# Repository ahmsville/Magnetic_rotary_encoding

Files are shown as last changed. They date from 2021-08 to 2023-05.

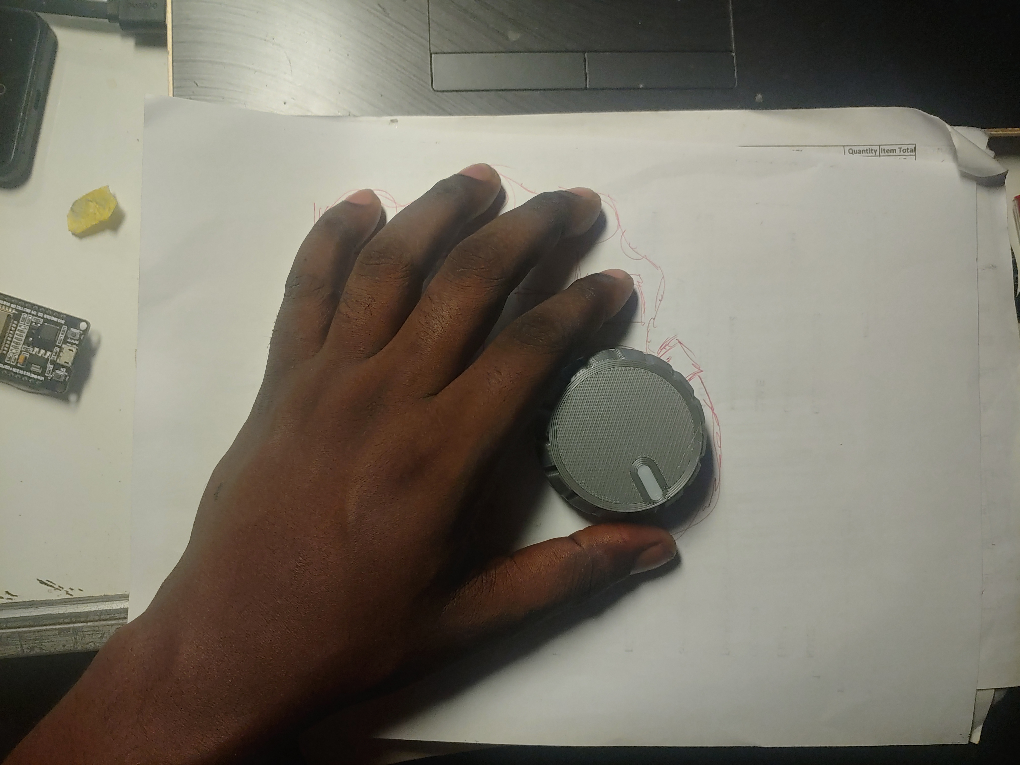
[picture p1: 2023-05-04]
PICO DEV M3/PICO DEV M3 KEYPAD/20230124_191834_HDR.jpg

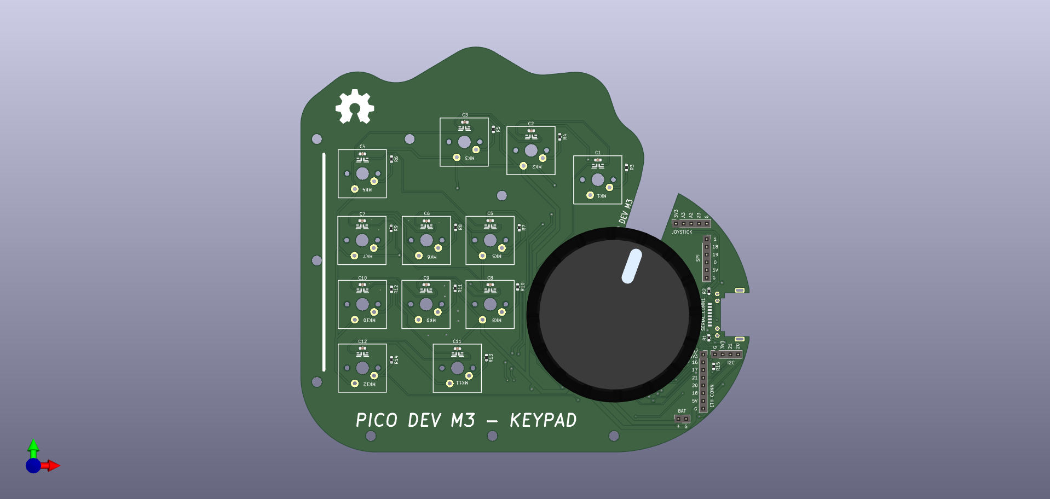
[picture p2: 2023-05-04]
PICO DEV M3/PICO DEV M3 KEYPAD/PICO DEV M3 KEYPAD.png

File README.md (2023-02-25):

# Magnetic_Rotary_Encoding

## Learn more about this project - 
 - https://www.ahmsvillelabs.io/projects/magnetic-rotary-encoding
 - https://youtu.be/atb6d4b-VYk
 - https://youtu.be/_1tGosBLRB0

## BUILD INSTRUCTIONS
 - https://www.ahmsvillelabs.io/magnetic-rotary-encoderbuild

# Hardware Options



 ## 1. Magnetic Rotary Encoder 
 This is standalone encoder made to connect to a seperate microcontroller like an Arduino board, this version has a base resolution of 72, extendable up to 72000 steps per revolution.
 magnetic rotary encoder pinout

 ### Features:
- Capacitive touch / button input
- Addressable Led ring (18 LEDs)
 ### Supported Boards / Platform:
- **All Arduino Boards** 
- **Raspberry Pi Pico C/C++ SDK** 
- **All Micropython-Supported Boards**

## 2. Magnetic Rotary Encoder MINI 
 This is standalone encoder similar to the first option, only with a small form factor, this version has a base resolution of 36, extendable up to 36000 steps per revolution.
 magnetic rotary encoder mini pinout

  ### Features:
- Capacitive touch / button input
- Addressable Led ring (12 LEDs)
 ### Supported Boards / Platform:
- **All Arduino Boards** 
- **Raspberry Pi Pico C/C++ SDK** 
- **All Micropython-Supported Boards**

## [3. Pico Dev M3](https://github.com/ahmsville/Magnetic_rotary_encoding/tree/master/PICO%20DEV%20M3) 
 This is a full fledged development board combined with the magnetic rotary encoder, its built with the Raspberry Pi RP2040 microcontroller chip with a base resolution of 36, extendable up to 36000 steps per revolution.
 pico dev m3 pinout

  ### Features:
- RP2040 chip, Dual-core Arm Cortex-M0+ processor at 133 MHz
- 264kB on-chip SRAM
- 128Mb on-board QSPI flash
- 19 multifunction GPIO pins, with 2 analog inputs
- 2 UARTs
- 2 SPI controllers
- 2 I2C controllers
- 16 PWM channels
- USB 1.1 controller with host and device support
- 8 PIO state machines
- USB type C
- Lipo charging
- onboard Button input
- Addressable Led ring (18 LEDs)
 ### Supported Platform:
- **RP2040 C/C++ SDK** 
- **Micropython**

# How to connect and use the [Ahmsville labs magnetic rotary encoder](https://www.tindie.com/products/22156/).

There are three ways to connect the magnetic rotary encoder, all with their benefits and draw backs.

## 1. Analog only Detection: 

in this mode the library uses just the signals from the hall effect sensors to make sense of the rotation of the encoder. the benefit of this mode is that you only need two analog pins to do all the rotation encoding, also been analog means you can use the libraries built in interpolation mode for an extremely high and granular resolution. The drawback is, this mode requires constant polling of the sensors which is not ideal for a complex system, also if the board does not have analog pins or if your setup cannot spare any of them, then you cannot use this mode.

## Connection

To use this mode, simply connect ENC-1 and ENC-2 to two analog input pins, you may also connect the LED pin to any available pin on the board. VCC  should be connected to the same voltage level used by the microcontroller on the boards, so power the encoder with 5v if the board uses 5v, and power it with 3.3v it the board uses 3.3v, you should offcus also connect the GND pin.

Asset 1

## Code

To test the example code, all you have to do is activate the analog only mode and change the pin assignment according to your connections. For the mode, you have the option to choose continuous rotation detection which returns a continuous count in either direction, or absolute positioning, which returns a value within the encoder’s base resolution, you can also choose the extended interpolated resolution mode for a super-duper high resolution.

## C/C++

```c++
#define ENCMODE 1 // BASE RESOLUTION ANALOG ONLY
//#define ENCMODE 2 // BASE RESOLUTION ANALOG ONLY ABSOLUTE POSITIONING
//#define ENCMODE 3 // EXTENDED RESOLUTION ANALOG ONLY
//#define ENCMODE 4 // BASE RESOLUTION ANALOG AND DIGITAL
//#define ENCMODE 5 // BASE RESOLUTION ANALOG AND DIGITAL ABSOLUTE POSITIONING
//#define ENCMODE 6 // EXTENDED RESOLUTION ANALOG AND DIGITAL
//#define ENCMODE 7 // BASE RESOLUTION DIGITAL ONLY
//#define ENCMODE 8 // BASE RESOLUTION DIGITAL ONLY ABSOLUTE POSITIONING
```

```c++
#define E1_ADC_PIN 26 // ADC PIN for hall sensor 1
#define E2_ADC_PIN 27 // ADC PIN for hall sensor 2
```

## MicroPython

```python
ENCMODE = 1 # BASE RESOLUTION ANALOG ONLY
#ENCMODE  = 2 # BASE RESOLUTION ANALOG ONLY ABSOLUTE POSITIONING
#ENCMODE  = 3 # EXTENDED RESOLUTION ANALOG ONLY
#ENCMODE  = 4 # BASE RESOLUTION ANALOG AND DIGITAL
#ENCMODE  = 5 # BASE RESOLUTION ANALOG AND DIGITAL ABSOLUTE POSITIONING
#ENCMODE  = 6 # EXTENDED RESOLUTION ANALOG AND DIGITAL
#ENCMODE  = 7 # BASE RESOLUTION DIGITAL ONLY
#ENCMODE  = 8 # BASE RESOLUTION DIGITAL ONLY ABSOLUTE POSITIONING
```

```python
E1_ADC_PIN = 26  # ADC PIN for hall sensor 1
E2_ADC_PIN = 27  # ADC PIN for hall sensor 2
```

## 2. Analog and Digital Detection: 

in this mode the library uses the signals from the hall effect sensors together with two additional digital interrupt enabled input pins. This mode has all the same features and benefits as the analog only detection mode without the need for constant polling of the hall effect sensors, this is extremely usefull for complex systems, as the interrupt pins notify the code of when a rotation occurs, so constant polling is not needed, this mode is in fact the mode used on the [Ahmsville Dial V2](https://youtu.be/yGbshYLfDnc).
Please note that the code will return to constant polling if you select the Extended Resolution mode, since this process requires interpolation between the encoder’s steps.

## Connection

To use this mode, simply connect ENC-1 and ENC-2 to two analog input pins, and E1-INT1 and E2-INT1 to two interrupt enabled pins on the board, you may also connect the LED pin to any available pins on the board. VCC  should be connected to the same voltage level used by the microcontroller on the boards, so power the encoder with 5v if the board uses 5v, and power it with 3.3v it the board uses 3.3v, you should offcus also connect the GND pin.

Asset 2

Depending on your encoder version, you may also need to bridge the config pads on the PCB to use this mode.
ASDADASDASDASDAS

## Code

To test the code, all you have to do is activate the analog and digital mode and also change the pin assignment according to your connections. For this mode, you also have the option to choose continuous rotation detection which returns a continuous count in either direction, or absolute positioning, which returns a value within the encoder’s base resolution, you can also choose the extended interpolated resolution mode for a super-duper high resolution.

## C/C++

```c++
//#define ENCMODE 1 // BASE RESOLUTION ANALOG ONLY
//#define ENCMODE 2 // BASE RESOLUTION ANALOG ONLY ABSOLUTE POSITIONING
//#define ENCMODE 3 // EXTENDED RESOLUTION ANALOG ONLY
#define ENCMODE 4 // BASE RESOLUTION ANALOG AND DIGITAL
//#define ENCMODE 5 // BASE RESOLUTION ANALOG AND DIGITAL ABSOLUTE POSITIONING
//#define ENCMODE 6 // EXTENDED RESOLUTION ANALOG AND DIGITAL
//#define ENCMODE 7 // BASE RESOLUTION DIGITAL ONLY
//#define ENCMODE 8 // BASE RESOLUTION DIGITAL ONLY ABSOLUTE POSITIONING
```

```c++
#define E1_INT1 16 // hall sensor 1 interrupt pin 1
#define E2_INT1 18 // hall sensor 2 interrupt pin 1

#define E1_ADC_PIN 26 // ADC PIN for hall sensor 1
#define E2_ADC_PIN 27 // ADC PIN for hall sensor 2
```

## MicroPython

```python
#ENCMODE = 1 # BASE RESOLUTION ANALOG ONLY
#ENCMODE  = 2 # BASE RESOLUTION ANALOG ONLY ABSOLUTE POSITIONING
#ENCMODE  = 3 # EXTENDED RESOLUTION ANALOG ONLY
ENCMODE  = 4 # BASE RESOLUTION ANALOG AND DIGITAL
#ENCMODE  = 5 # BASE RESOLUTION ANALOG AND DIGITAL ABSOLUTE POSITIONING
#ENCMODE  = 6 # EXTENDED RESOLUTION ANALOG AND DIGITAL
#ENCMODE  = 7 # BASE RESOLUTION DIGITAL ONLY
#ENCMODE  = 8 # BASE RESOLUTION DIGITAL ONLY ABSOLUTE POSITIONING
```

```python
E1_INT1 = 16 # hall sensor 1 interrupt pin 1
E2_INT1 = 18 # hall sensor 2 interrupt pin 1

E1_ADC_PIN = 26 # ADC PIN for hall sensor 1
E2_ADC_PIN = 27 # ADC PIN for hall sensor 2
```

## 3. Digital only Detection: 

in this mode the library uses only digital interrupt enabled input pins; four of them. This mode is similar in operation to traditional rotary switches, the analog signals from the hall effect sensors have been converted to digital signals using comparators, so no analog input pins are required. This mode was developed for systems that don’t have or cannot spare analog input pins, its also the fastest mode and requires zero polling, which is why I used it to encode the [Pick N Place Wheel](https://youtu.be/MtNO8-5vCqg). 
Because this mode uses digital signals alone, you cannot use the interpolated extended resolution mode that is available in the previous modes.

## Connection

To use this mode, simply connect E1-INT1, E1-INT2, E2-INT1 and E2-INT2 to four interrupt enabled pins on the board, you may also connect the LED pin to any available pins on the board. VCC  should be connected to the same voltage level used by the microcontroller on the boards, so power the encoder with 5v if the board uses 5v, and power it with 3.3v it the board uses 3.3v,  also connect the GND pin.

Asset 3

## Code

To test the code, all you have to do is activate the digital only mode and also change the pin assignments according to your connections. For this mode, you have the option to choose continuous rotation detection which returns a continuous count in either direction, or absolute positioning, which returns a value within the encoder’s base resolution.

## C/C++

```c++
//#define ENCMODE 1 // BASE RESOLUTION ANALOG ONLY
//#define ENCMODE 2 // BASE RESOLUTION ANALOG ONLY ABSOLUTE POSITIONING
//#define ENCMODE 3 // EXTENDED RESOLUTION ANALOG ONLY
//#define ENCMODE 4 // BASE RESOLUTION ANALOG AND DIGITAL
//#define ENCMODE 5 // BASE RESOLUTION ANALOG AND DIGITAL ABSOLUTE POSITIONING
//#define ENCMODE 6 // EXTENDED RESOLUTION ANALOG AND DIGITAL
#define ENCMODE 7 // BASE RESOLUTION DIGITAL ONLY
//#define ENCMODE 8 // BASE RESOLUTION DIGITAL ONLY ABSOLUTE POSITIONING
```

```c++
#define E1_INT1 16 // hall sensor 1 interrupt pin 1
#define E1_INT2 17 // hall sensor 1 interrupt pin 2
#define E2_INT1 18 // hall sensor 2 interrupt pin 1
#define E2_INT2 19 // hall sensor 2 interrupt pin 2
```

## MicroPython

```python
#ENCMODE = 1 # BASE RESOLUTION ANALOG ONLY
#ENCMODE  = 2 # BASE RESOLUTION ANALOG ONLY ABSOLUTE POSITIONING
#ENCMODE  = 3 # EXTENDED RESOLUTION ANALOG ONLY
ENCMODE  = 4 # BASE RESOLUTION ANALOG AND DIGITAL
#ENCMODE  = 5 # BASE RESOLUTION ANALOG AND DIGITAL ABSOLUTE POSITIONING
#ENCMODE  = 6 # EXTENDED RESOLUTION ANALOG AND DIGITAL
#ENCMODE  = 7 # BASE RESOLUTION DIGITAL ONLY
#ENCMODE  = 8 # BASE RESOLUTION DIGITAL ONLY ABSOLUTE POSITIONING
```

```python
E1_INT1 = 16  # hall sensor 1 interrupt pin 1
E1_INT2 = 17  # hall sensor 1 interrupt pin 2
E2_INT1 = 18  # hall sensor 2 interrupt pin 1
E2_INT2 = 19  # hall sensor 2 interrupt pin 2
```

# Complimentary Input on the Encoder

You have two options when it comes to complimentary input on the encoder, you can choose to use capacitive touch or a normal push button, both the capacitive touch and the push button will be included with the kit if you buy it from [my store](https://www.tindie.com/products/22156/).
To use capacitive touch, you will need an Arduino board, if you use other development boards like the ESP32 or Raspberry PI Pico, you will have to use the push button.

SAGSAFFF
zczczczcc

## Capacitive touch
To use the capacitive touch on an Arduino, you must have assembled the encoder according to the instructions, so that you can simply connect CT1 and CT2 to two available pins and then update the pin assignment in the example code accordingly.

## C/C++

```c++
#define CT1 5 // CAPACITIVE TOUCH (CT1)
#define CT2 6 // CAPACITIVE TOUCH (CT2)
```

## Push button
To use the push button, you should solder the included button to the encoder board and then connect only CT1 to an available pin on the development board.

## C/C++

```c++
#define CT1 15 // PUSH BUTTON (CT1)
```

## MicroPython

```python
CT1 = 15 # PUSH BUTTON (CT1)
```

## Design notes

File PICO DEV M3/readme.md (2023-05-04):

# PICO DEV M3



The **Pico Dev M3** is a development board based on Raspberry Pi's **RP2040 microcontrolle**r chip, the board is also a high-resolution **magnetic rotary encoder** when paired with a few 3D printed parts, which makes this the perfect board for applications and projects that can benefit from having a rotary encoder, a good example is making macro pads, and other similar secondary controllers.

## **Board Features**
- RP2040 chip, Dual-core Arm Cortex-M0+ processor at 133 MHz
- 264kB on-chip SRAM
- 128Mb on-board QSPI flash
- 19 multifunction GPIO pins, with 2 analog inputs
- 2 UARTs
- 2 SPI controllers
- 2 I2C controllers
- 16 PWM channels
- USB 1.1 controller with host and device support
- 8 PIO state machines
- USB type C
- Lipo charging
- onboard Button input
- Addressable Led ring (18 LEDs)

## **Encoder Features**

- The onboard encoder features a base resolution of **36 steps, extending up to 36000** steps per revolution.
- There’s also a ring of **18 individually addressable LEDs** on board.
- Features a ball bearing which gives the encoder a significantly smoother feel compared to traditional rotary encoders.
- Customizable 3d printed encoder. 
- Implementing the encoder is also really straightforward using the dedicated Libraries and Sample Codes
- Easy mounting options

### **Programming Language:**

- **RP2040 C/C++ SDK** 
- **Micropython**

pico dev m3 pinout

## **Sample Projects Based on the PICO DEV M3:**

ZVE00216 (3)

- **Pico Dev M3 Keypad** 

ZVE00234 (2)

This is a 12-key macropod that uses the Pico dev m3 as its controller, the breakout board features backlit keys, headers for connecting I2C, SPI, and UART peripherals, and a header for connecting a joystick module to the Pico dev m3, you can power the keypad from the type c port on the pico dev m3 board or with a Lipo battery connected to the BAT header, taking advantage of the Lipo charge controller built into the pico dev m3.
- **PIO Stepper Controller**

ZVE00231 (2)

This breakout board allows you to use this Programmable IO (PIO) on the RP2040 chip on the Pico dev m3 to individually control 3 stepper motors. This board can be used to control any 3-axis motion system, robot, or custom mechanism.

## BUILD INSTRUCTIONS
 - https://www.ahmsvillelabs.io/magnetic-rotary-encoderbuild/pico-dev-m3

### **Encoder Assembly:**

- Sandwich the pico dev m3 board between the **BOARD BUTTON** and **BOARD TOP** 3D printed parts, and secure them together using 3 **M1.4x6mm** self-tapping screws.

Capture

CaptureXCXC

- Attach **608 bearing (8x22x7)** to the assembly and secure it with the **BEARING HOLDER** part and 1 **M2x8mm** self-tapping screw.

CapturZDCe

- Install **(18pcs) 3x1mm** neodymium magnets to the KNOB in an alternating pole configuration.
Depending on your 3D printer's tolerance you may use super glue to secure the magnets, but if the holes turn out as the perfect size, a simple press-fit is sufficient.

CaptuGGre

- Attach the knob to the bearing.

CaptFHNFure

- For Flexibility, you may print the **BUTTON BASE** file this allows the pico dev m3 encoder and button to be used conviniently, the button base attaches to the pico dev encoder via 2 **M2x8mm** selftapping screws.

Capgfgture

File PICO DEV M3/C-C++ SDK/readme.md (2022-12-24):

# Pico Dev M3 C/C++ SDK

The board will come with a default firmware loaded, so you should be able to just connect it to a computer and see the output from a serial terminal like putty or arduino's serial monitor. The default firmware is in C/C++ and you can download the UF2 file [**here.**](https://github.com/ahmsville/Magnetic_rotary_encoding/tree/master/PICO%20DEV%20M3/C-C%2B%2B%20SDK/PICO%20DEV%20M3/build) 

To use the C/C++ code for the pico dev m3, you should alredy have your computer setup to program a Raspberry pi pico using the C/C++ SDK, if not, i recommend watching this [video from Learn Embedded Systems](https://www.youtube.com/watch?v=mUF9xjDtFfY) or you can follow the official instructions at [**Raspberry Pi Documentation.**](https://www.raspberrypi.com/documentation/microcontrollers/c_sdk.html)

This page contains the project folder for the pico dev m3, you can download it and build it yourself, i personally use visual studio code to build my RP2040 projects, and its just a matter of adding the folder to the workspace and allowing the project to configure itself, you can then click on build.
Captuzvdfdsfsdfre

To load the compiled firmware to the pico dev m3, simply copy the generated UF2 file located in the build folder to the board by connecting to the board via the usb type c port while holding the BOOTSEL button at the back of the board, reference the pinout diagram.

## Changing the encoding method used on the board.

Please see the main [Magnetic rotary encoder](https://github.com/ahmsville/Magnetic_rotary_encoding) page for details on the differences between the modes listed below.

To switch modes, simply uncomment one of this lines in the example code

```C++
// #define ENCMODE 1 // BASE RESOLUTION ANALOG ONLY
#define ENCMODE 2 // BASE RESOLUTION ANALOG ONLY ABSOLUTE POSITIONING
// #define ENCMODE 3 // EXTENDED RESOLUTION ANALOG ONLY
// #define ENCMODE 4 // EXTENDED RESOLUTION ANALOG ONLY ABSOLUTE POSITIONING
// #define ENCMODE 5 // BASE RESOLUTION ANALOG AND DIGITAL
// #define ENCMODE 6 // BASE RESOLUTION ANALOG AND DIGITAL ABSOLUTE POSITIONING
// #define ENCMODE 7 // EXTENDED RESOLUTION ANALOG AND DIGITAL
// #define ENCMODE 8 // EXTENDED RESOLUTION ANALOG AND DIGITAL ABSOLUTE POSITIONING
// #define ENCMODE 9 // BASE RESOLUTION DIGITAL ONLY
// #define ENCMODE 10 // BASE RESOLUTION DIGITAL ONLY ABSOLUTE POSITIONING
```

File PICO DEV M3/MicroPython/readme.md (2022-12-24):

# Pico Dev M3 Micropython Setup

The board will come with a default firmware loaded, so you should be able to just connect it to a computer and see the output from a serial terminal like putty or arduino's serial monitor. The default firmware is in C/C++ and you can download the UF2 file [**here.**](https://github.com/ahmsville/Magnetic_rotary_encoding/tree/master/PICO%20DEV%20M3/C-C%2B%2B%20SDK/PICO%20DEV%20M3/build) 

## Step 1

Download the micropython uf2 firmware for the raspberry pi pico [**here**](https://micropython.org/download/rp2-pico/), and copy it into the pico dev m3.

To get the pico dev m3 to show up as a storage device on the computer, connect to the board via the usb type c port while holding the BOOTSEL button at the back of the board, reference the pinout diagram.

## Step 2

Download the python files on this page to a folder on your computer.

## Step 3

Open **MagneticRotaryEncoder.py** in thonny ide, go to file, save copy, thonny will ask for a location to save the file, select Raspberry Pi Pico, save the file on the pico dev m3 with the name **"MagneticRotaryEncoder.py"**

Capturesds

## Step 4

Open **MagEncoder Example.py** in a new thonny ide window or tab, click on run script, the pico dev m3 led ring should turn on and you will see the encoder's counting value in thonny's terminal/shell as you rotate the knob on the pico dev m3. 

Capturxfdfe

## Changing the encoding method used on the board.

Please see the main [Magnetic rotary encoder](https://github.com/ahmsville/Magnetic_rotary_encoding) page for details on the differences between the modes listed below.

To switch modes, simply uncomment one of this lines in the example code

```python
#ENCMODE = 1 # BASE RESOLUTION ANALOG ONLY
#ENCMODE  = 2 # BASE RESOLUTION ANALOG ONLY ABSOLUTE POSITIONING
#ENCMODE  = 3 # EXTENDED RESOLUTION ANALOG ONLY
#ENCMODE  = 4 # BASE RESOLUTION ANALOG AND DIGITAL
#ENCMODE  = 5 # BASE RESOLUTION ANALOG AND DIGITAL ABSOLUTE POSITIONING
#ENCMODE  = 6 # EXTENDED RESOLUTION ANALOG AND DIGITAL
ENCMODE  = 7 # BASE RESOLUTION DIGITAL ONLY
#ENCMODE  = 8 # BASE RESOLUTION DIGITAL ONLY ABSOLUTE POSITIONING
```

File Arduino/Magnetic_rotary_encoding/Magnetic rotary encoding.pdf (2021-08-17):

## Magnetic rotary encoding

The method of detecting rotation that’s discused on this page was born from my need for a rotary encoding solution that’s contactless, continuous, bidirectional, cheap and easily customizable for different project types.

The goal of having a contactless rotation detection is mainly to alleviate the durability issues associated with traditional rotary encoding components like potentiometers and rotary encoders.
How it works.

The main idea here is to attach magnets with alternating poles to the rotating body, and then use two hall effect sensors to read the analog value changes that occurs when the body rotates. With this setup the circuit/sensors is completely isolated, and makes no physical contact with the rotating body.

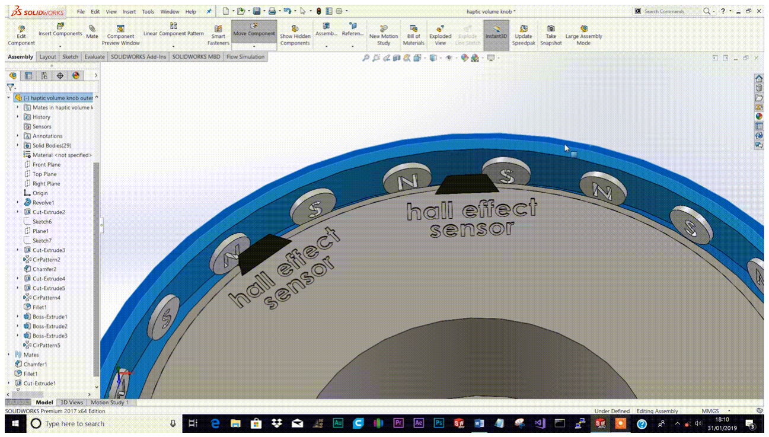
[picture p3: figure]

The animation above shows the basic operation of this setup, the outer ring with the alternating magnetic poles represents the moving body that revolves around two stationary hall effect sensors, a real life implementation is shown below, the magnets are glued to the outer ring, and the sensors are glued to the inner one…

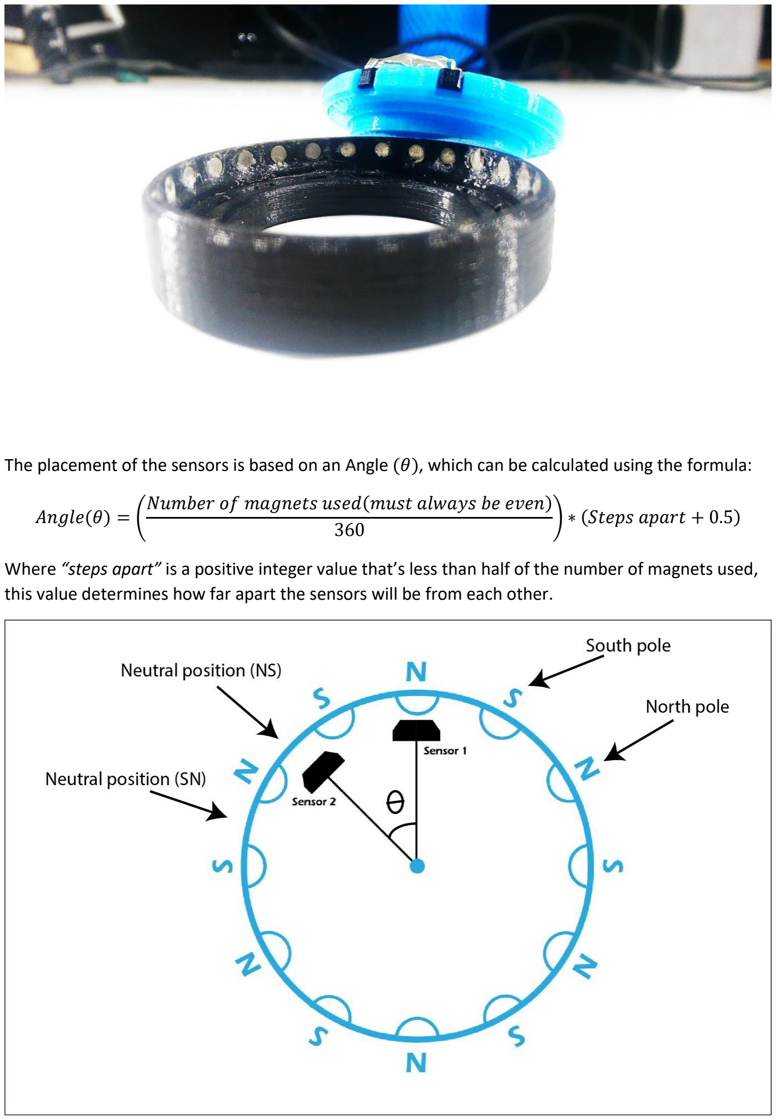
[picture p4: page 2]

The placement of the sensors is based on an Angle (θ), which can be calculated using the formula:

Angle(θ) = (
Number of magnets used(must always be even)
360 | ) ∗ (Steps apart + 0.5)

Where “steps apart” is a positive integer value that’s less than half of the number of magnets used, this value determines how far apart the sensors will be from each other.

The angle (θ) offsets the sensors from each other in such a way that one of them will always be in the neutral position whenever the other is facing either of the poles. from this arrangement, the following tables can be derived.

The tables show the state of each sensor with respect to the other.. so when sensor 1 is facing north, sensor 2 will be in the neutral position, which is represented as a zero on the tables. from that information, one can further deduce the state that represents one clockwise step and one anticlockwise step, based on the four possible start positions…

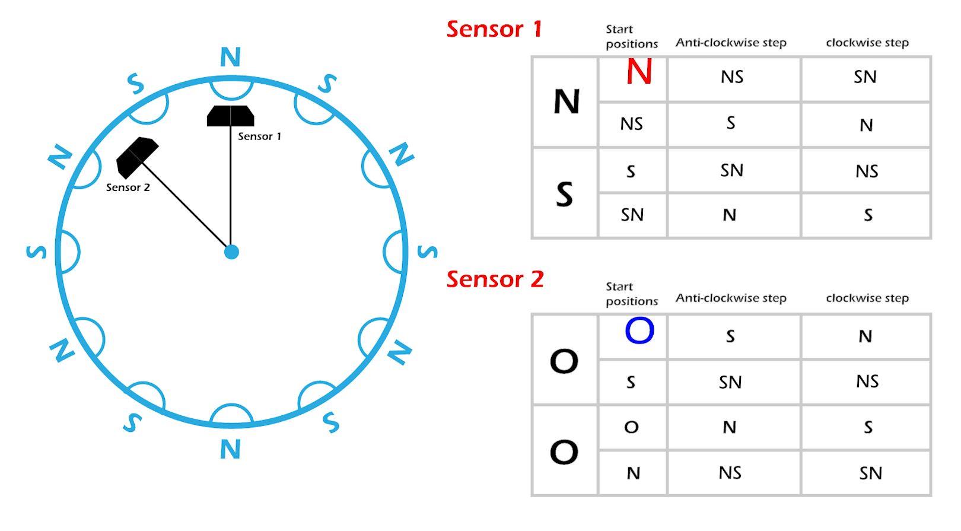
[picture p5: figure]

for example, if sensor 1 is currently in-between N and S, Its clear that if its state changes to S, the outer ring must have moved one step anticlockwise and if its state changes to N, it must have moved one step clockwise.

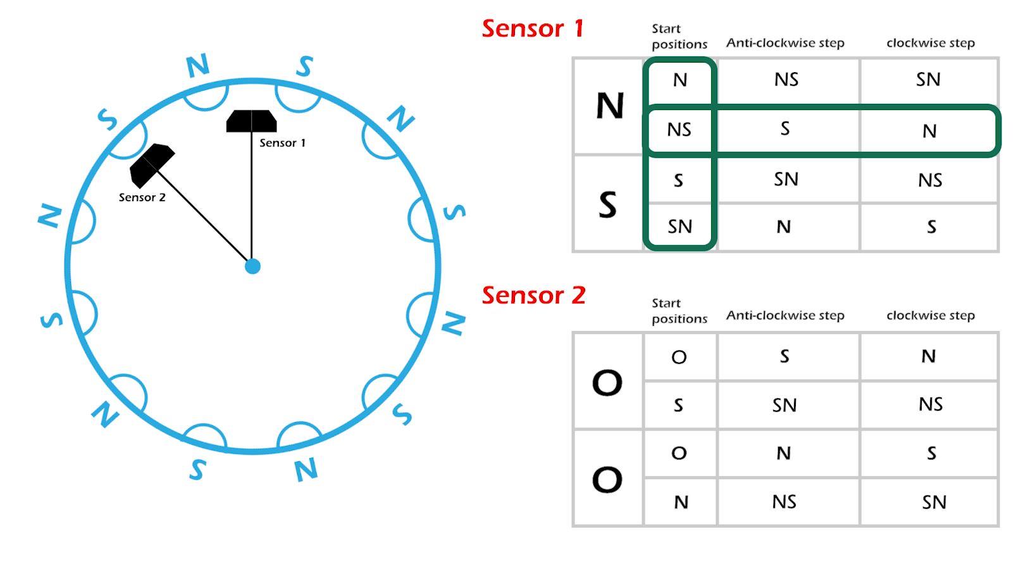
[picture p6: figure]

let’s say it did move clockwise to N, this becomes the new start position, and once again, one can tell that if its state changes to NS that’s an anticlockwise rotation and if it changes to SN, a clockwise rotation.

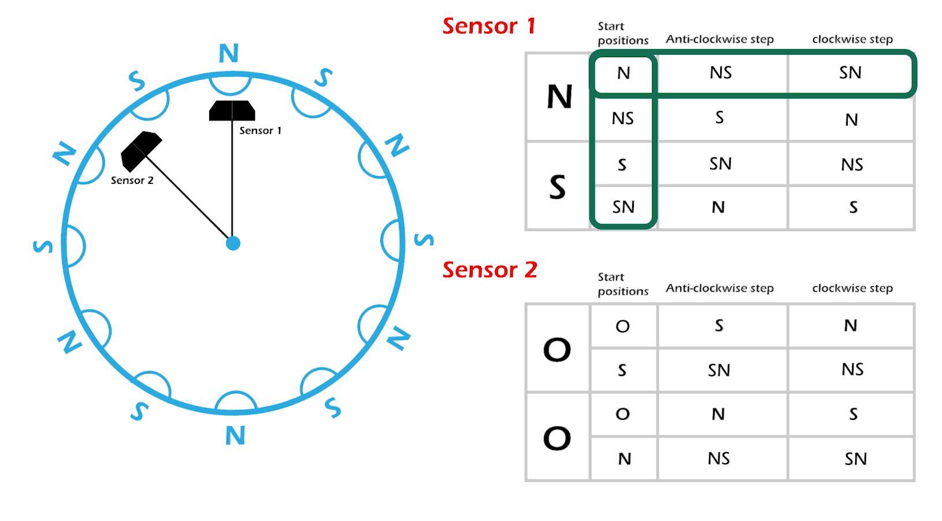
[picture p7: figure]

The continuous repetition of this process is how the rotations are registered.

Another thing worth mentioning is the operation of the hall effect sensors, the range of analog values from the sensor is divided into two, so the lower half could be assigned to the North pole and the upper half to the south, or vice versa.

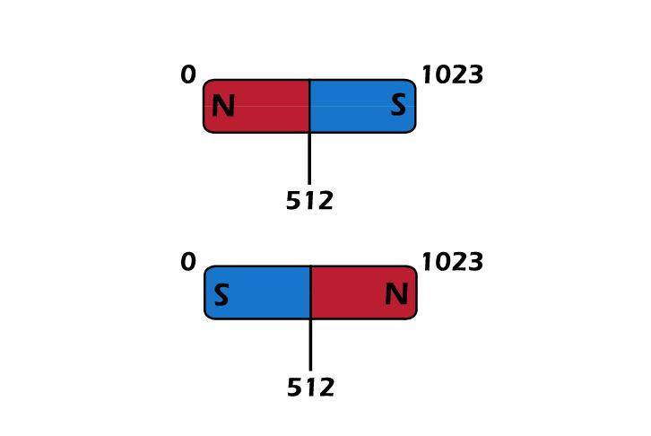
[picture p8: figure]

what this means is the middle position will always be the same value regardless of the orientation of the magnet, so NS, or SN, its all the same to the sensor… therefore all the “NS” and “SN” on the tables are all synonymous to the neutral position, this means each table only accounts for 50% of the data required to accurately detect the rotations… which is why this setup requires two sensors.

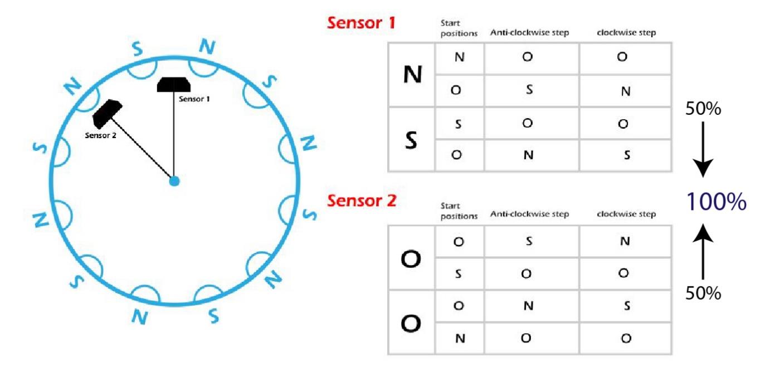
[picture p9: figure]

Please note that all the states indicated on the tables are representing a range of ADC values between 0 – 1023. For example:

- 0 – 400 represents the North pole of the magnet (N).
- 401 – 599 represents the Neutral state of the magnet (NS, SN and 0).
- 600 – 1023 represents the South pole of the magnet (S).

This values are important to the rotation detection algorithm of the MagRotaryEncoder library.

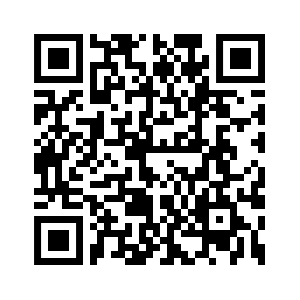
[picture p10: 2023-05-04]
PICO DEV M3/Pico Dev M3 Pio Stepper controller/frame (2).png

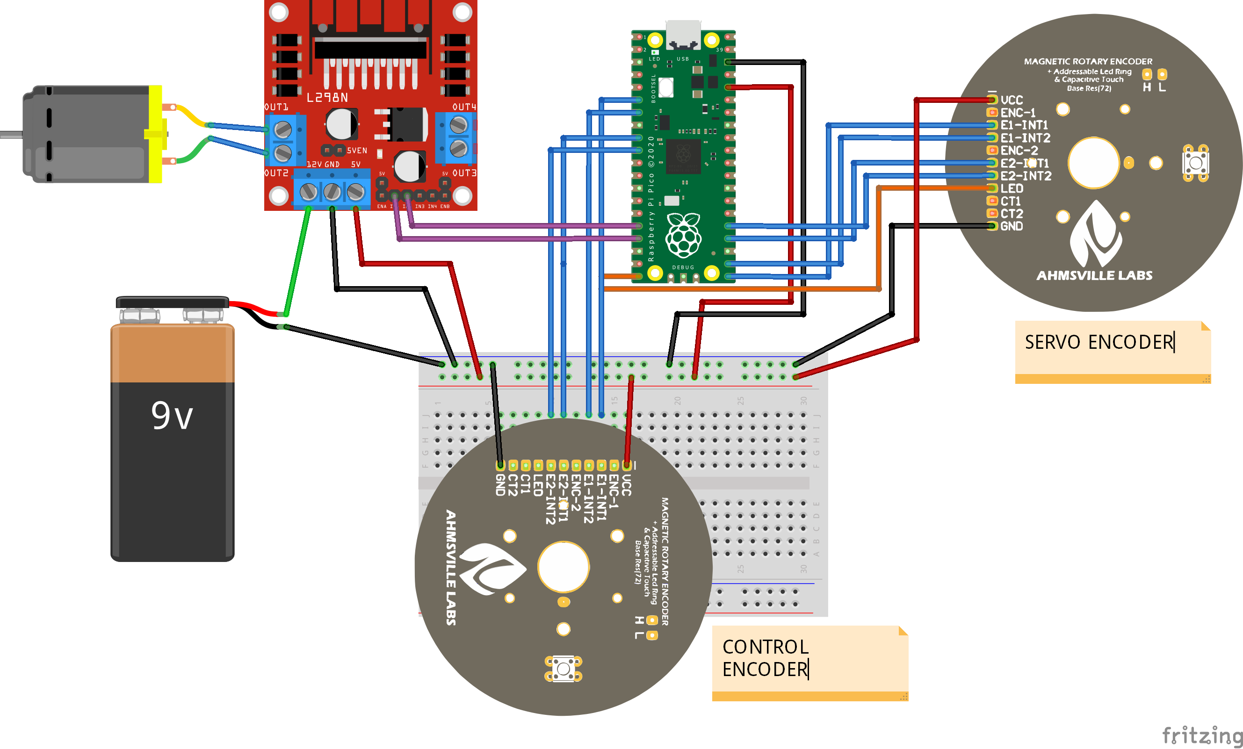
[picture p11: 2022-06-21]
Magnetic Encoder Servo Project/magnetic encoder servo fritzing_bb.png

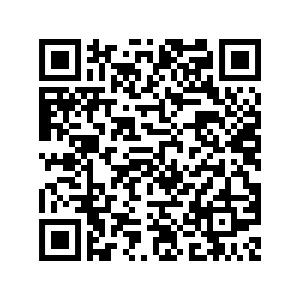
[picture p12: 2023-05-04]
PICO DEV M3/PICO DEV M3 KEYPAD/frame (5).png

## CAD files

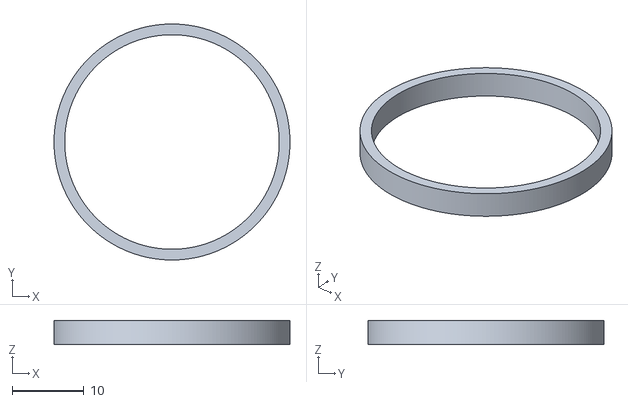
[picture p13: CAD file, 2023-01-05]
CAD/Magnetic Rotary Encoder/DEFAULT SIZE/MAGNETIC ENCODER NORMAL - SPACER-1.STL
32.9 x 32.9 x 3.40

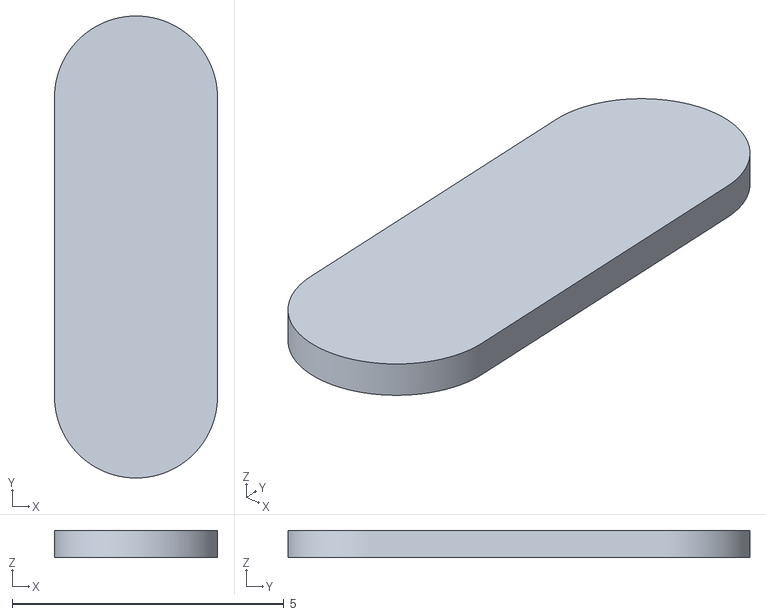
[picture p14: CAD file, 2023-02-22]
CAD/Magnetic Rotary Encoder/MINI ENCODER/INDEXED KNOB/MINI ENCODER - INDEXED KNOB SLOT.STL
3.00 x 8.50 x 0.5

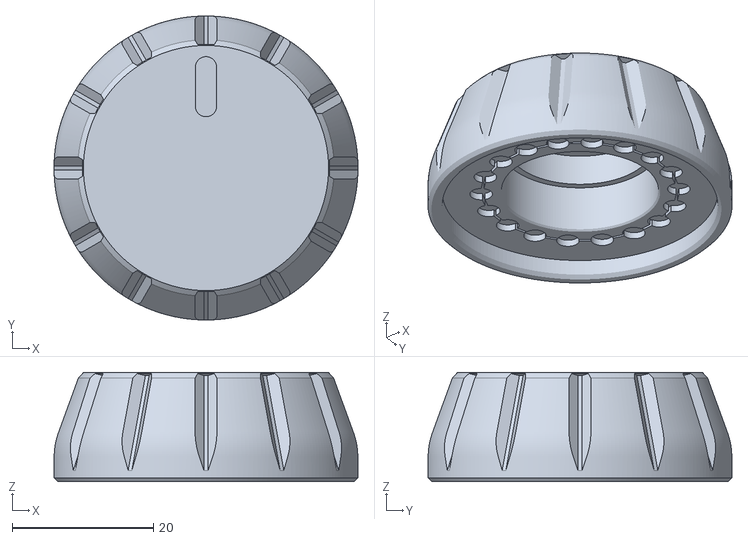
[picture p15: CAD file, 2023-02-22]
CAD/Magnetic Rotary Encoder/MINI ENCODER/MINI ENCODER- - KNOB-1.STL
43.0 x 43.0 x 15.4

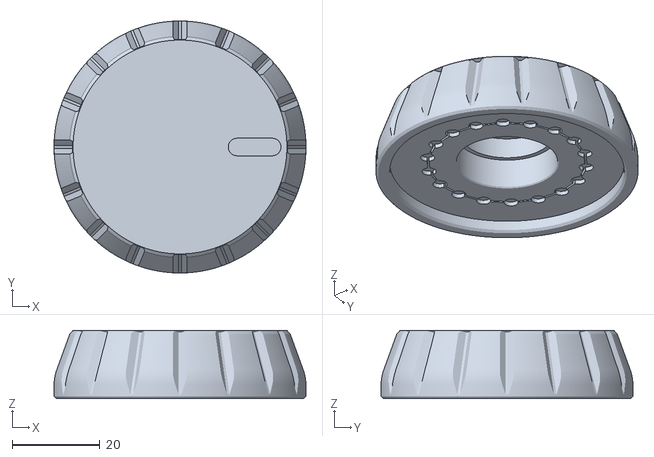
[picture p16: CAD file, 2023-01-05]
PICO DEV M3/3D Printing Files/RP2040 ENCODER - KNOB-1.STL
57.4 x 57.4 x 15.6

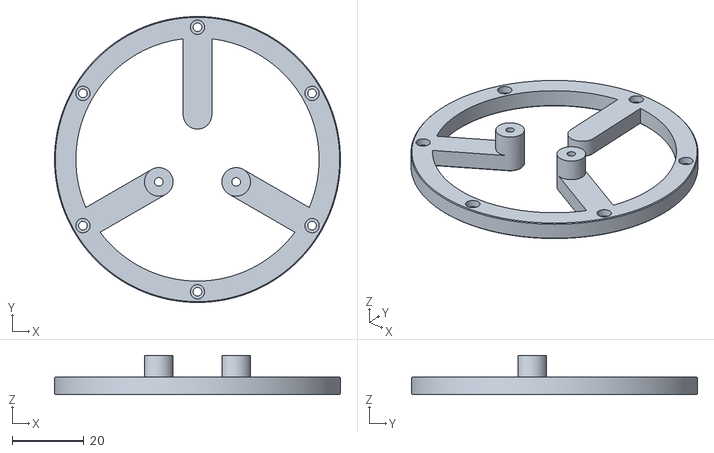
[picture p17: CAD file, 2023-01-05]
CAD/Magnetic Rotary Encoder/DEFAULT SIZE/MAGNETIC ENCODER NORMAL - MOUNTING BASE-1.STL
80.0 x 80.0 x 11.0

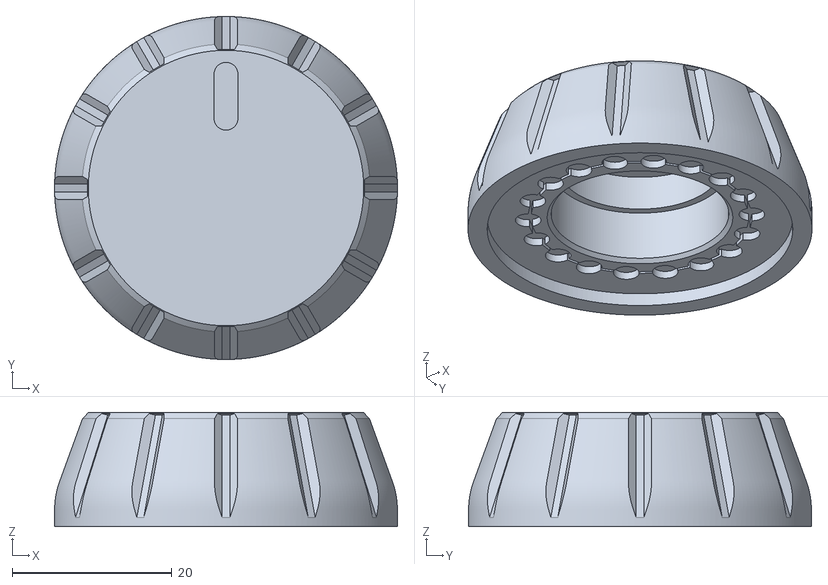
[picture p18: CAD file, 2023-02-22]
CAD/Magnetic Rotary Encoder/MINI ENCODER/INDEXED KNOB/MINI ENCODER - INDEXED KNOB.STL
43.0 x 43.0 x 14.3

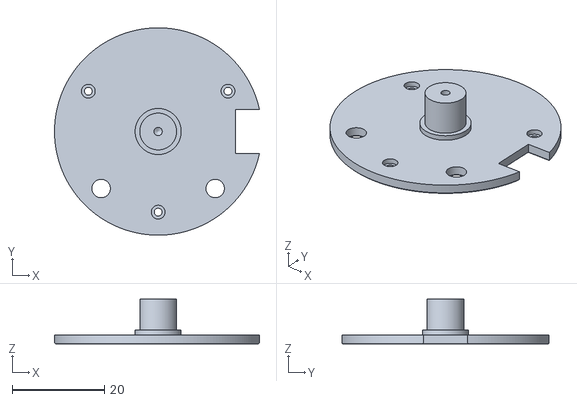
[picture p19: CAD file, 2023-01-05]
PICO DEV M3/3D Printing Files/RP2040 ENCODER - BOARD TOP-1.STL
44.5 x 45.0 x 9.76

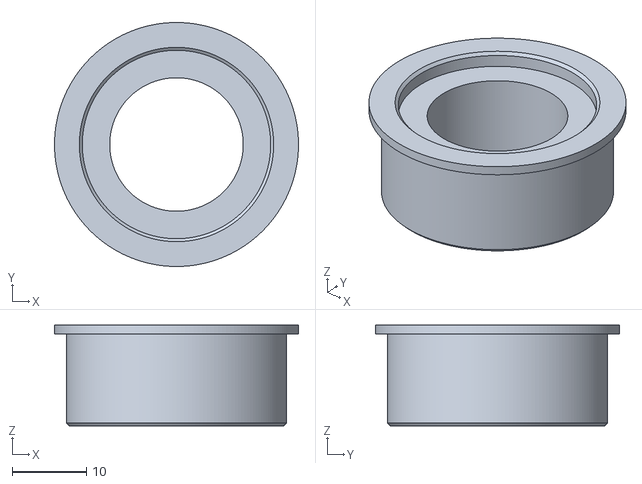
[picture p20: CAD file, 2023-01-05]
CAD/Magnetic Rotary Encoder/DEFAULT SIZE/MAGNETIC ENCODER NORMAL - BEARING HOLDER-1.STL
32.9 x 32.9 x 13.6

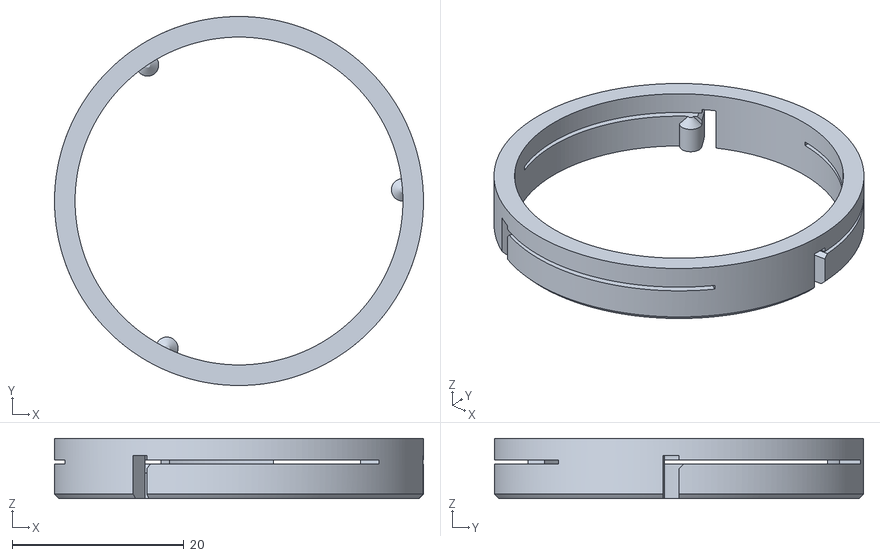
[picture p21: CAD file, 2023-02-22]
CAD/Magnetic Rotary Encoder/MINI ENCODER/INDEXED KNOB/MINI ENCODER - INDEXED KNOB WHITE BASE.STL
43.0 x 43.0 x 7.00

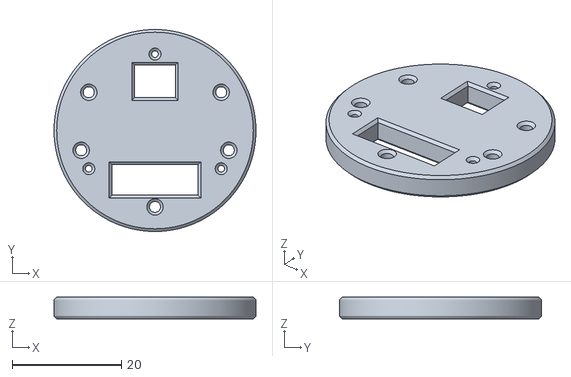
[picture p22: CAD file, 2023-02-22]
CAD/Magnetic Rotary Encoder/MINI ENCODER/MINI ENCODER- - BOARD BOTTOM-1.STL
37.0 x 37.0 x 4.00

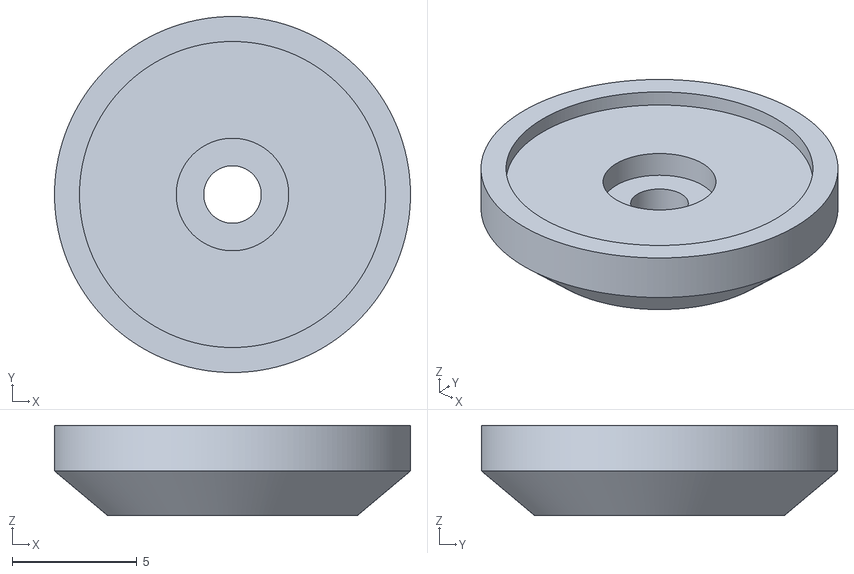
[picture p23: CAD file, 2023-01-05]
PICO DEV M3/3D Printing Files/RP2040 ENCODER - BEARING HOLDER-1.STL
14.2 x 14.2 x 3.60

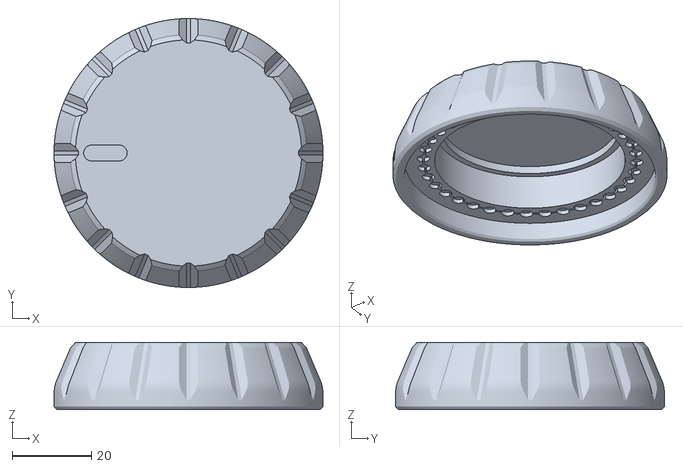
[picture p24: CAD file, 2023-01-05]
CAD/Magnetic Rotary Encoder/DEFAULT SIZE/MAGNETIC ENCODER NORMAL - KNOB-1.STL
68.0 x 68.0 x 17.0

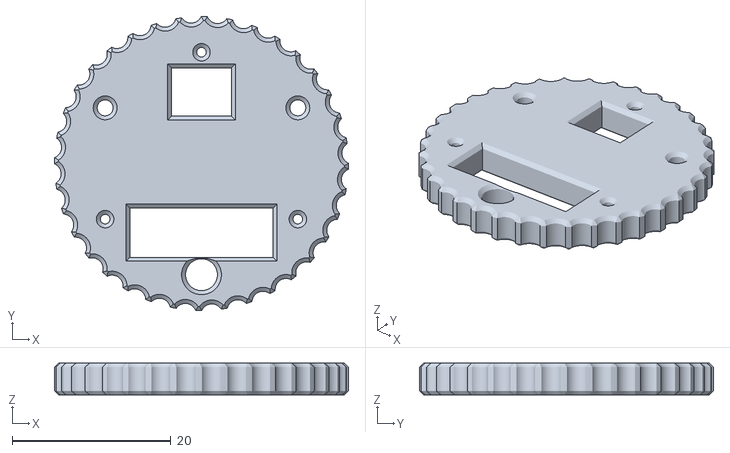
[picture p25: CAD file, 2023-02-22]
CAD/Magnetic Rotary Encoder/MINI ENCODER/INDEXED KNOB/MINI ENCODER - INDEXED BOARD BOTTOM.STL
37.0 x 37.0 x 4.00

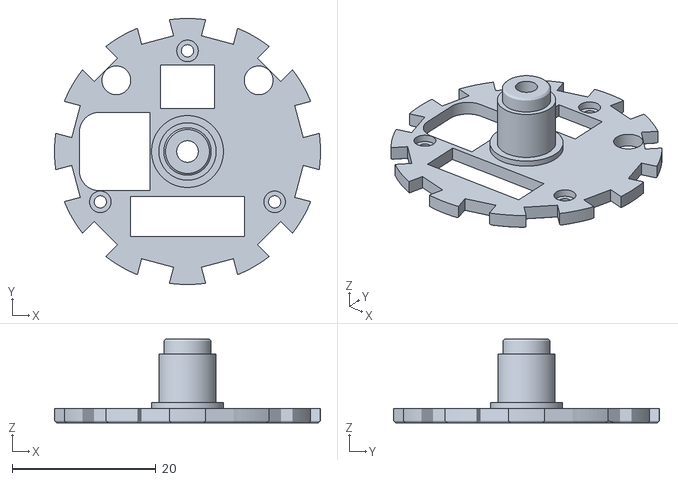
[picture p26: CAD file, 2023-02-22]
CAD/Magnetic Rotary Encoder/MINI ENCODER/MINI ENCODER- - BOARD TOP-1.STL
37.0 x 37.0 x 11.6

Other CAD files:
CAD/Magnetic Rotary Encoder/MINI ENCODER/MINI ENCODER- - SLOT-1.STL
PICO DEV M3/3D Printing Files/RP2040 ENCODER - BUTTON BASE-1.STL
CAD/Magnetic Rotary Encoder/DEFAULT SIZE/MAGNETIC ENCODER NORMAL - SLOT-1.STL
CAD/Magnetic Rotary Encoder/MINI ENCODER/MINI ENCODER- - BEARING TOP HOLDER-1.STL
CAD/Magnetic Rotary Encoder/MINI ENCODER/MINI ENCODER- - MOUNTING BASE-1.STL
PICO DEV M3/3D Printing Files/RP2040 ENCODER - BOARD BUTTOM-1.STL
PICO DEV M3/3D Printing Files/RP2040 ENCODER - SLOT-1.STL

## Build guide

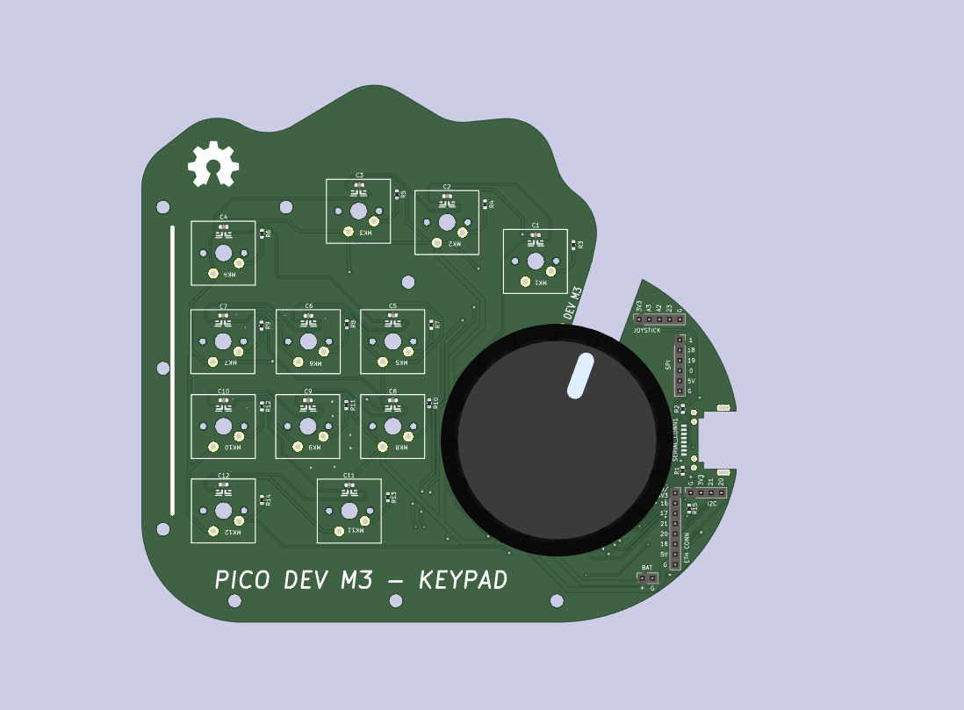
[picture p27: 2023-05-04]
PICO DEV M3/PICO DEV M3 KEYPAD/MANUFACTURING/PICO DEV M3 KEYPAD/Capture.PNG

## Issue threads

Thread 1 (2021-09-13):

Missing ADCRead.h

Lizard-King101, 2021-09-13:
Not sure what i'm missing but I was testing it out with both Arduino pro Micro and the Seeeduino XAIO. any help fixing this issue? I would really appreciate any info on the mysterious `ADCRead.h`

```
MagRotaryEncoding.h:13:10: fatal error: ADCRead.h: No such file or directory
 #include "ADCRead.h"
          ^~~~~~~~~~~
```
I tried looking for anything about ADCRead.h on google but hit a dead end. even tried using a library called ADC.h but that was Teensy only.

Lizard-King101, 2021-09-19:
@ahmsville you there buddy?

ahmsville, 2021-09-20:
Hi @Lizard-King101  apologies for the inconvenience, the ADCRead is on a separate repository,  but i have just updated the Magnetic rotary encoding repository to contain these file locally, so simply clone this repository again and you should be good to go.
If you have any other questions, please let me know.

Closed 2021-09-20.

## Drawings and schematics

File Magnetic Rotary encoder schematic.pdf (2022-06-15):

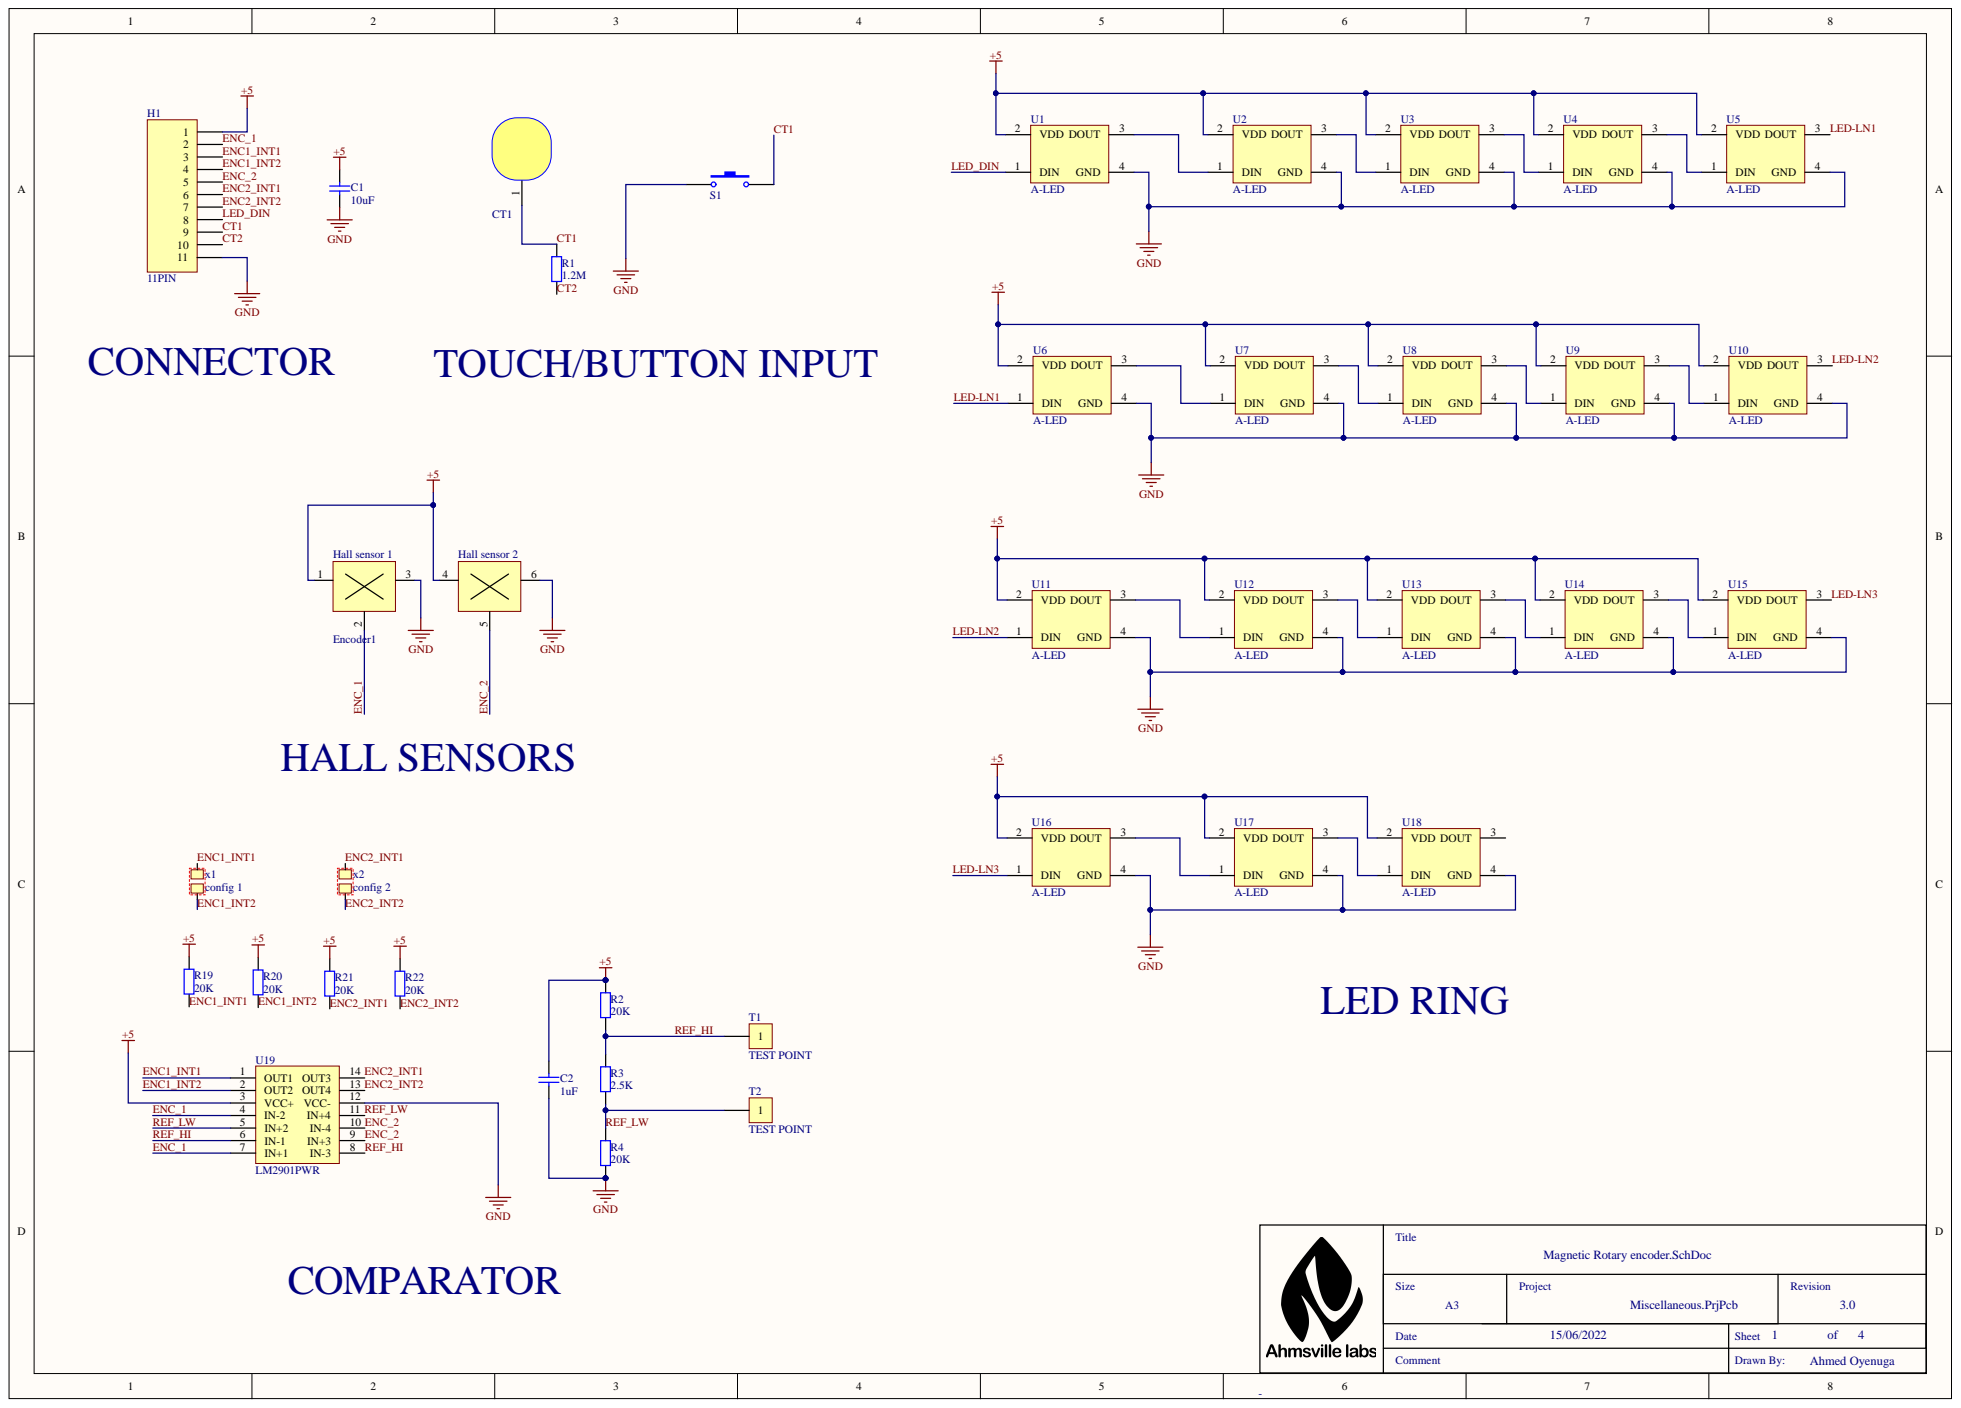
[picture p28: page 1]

Title Magnetic Rotary encoder.SchDoc

Size A3 | | Project Miscellaneous.PrjPcb | Revision 3.0

Date 15/06/2022 | Sheet 1 of 4

Comment | Ahmed Oyenuga Drawn By:

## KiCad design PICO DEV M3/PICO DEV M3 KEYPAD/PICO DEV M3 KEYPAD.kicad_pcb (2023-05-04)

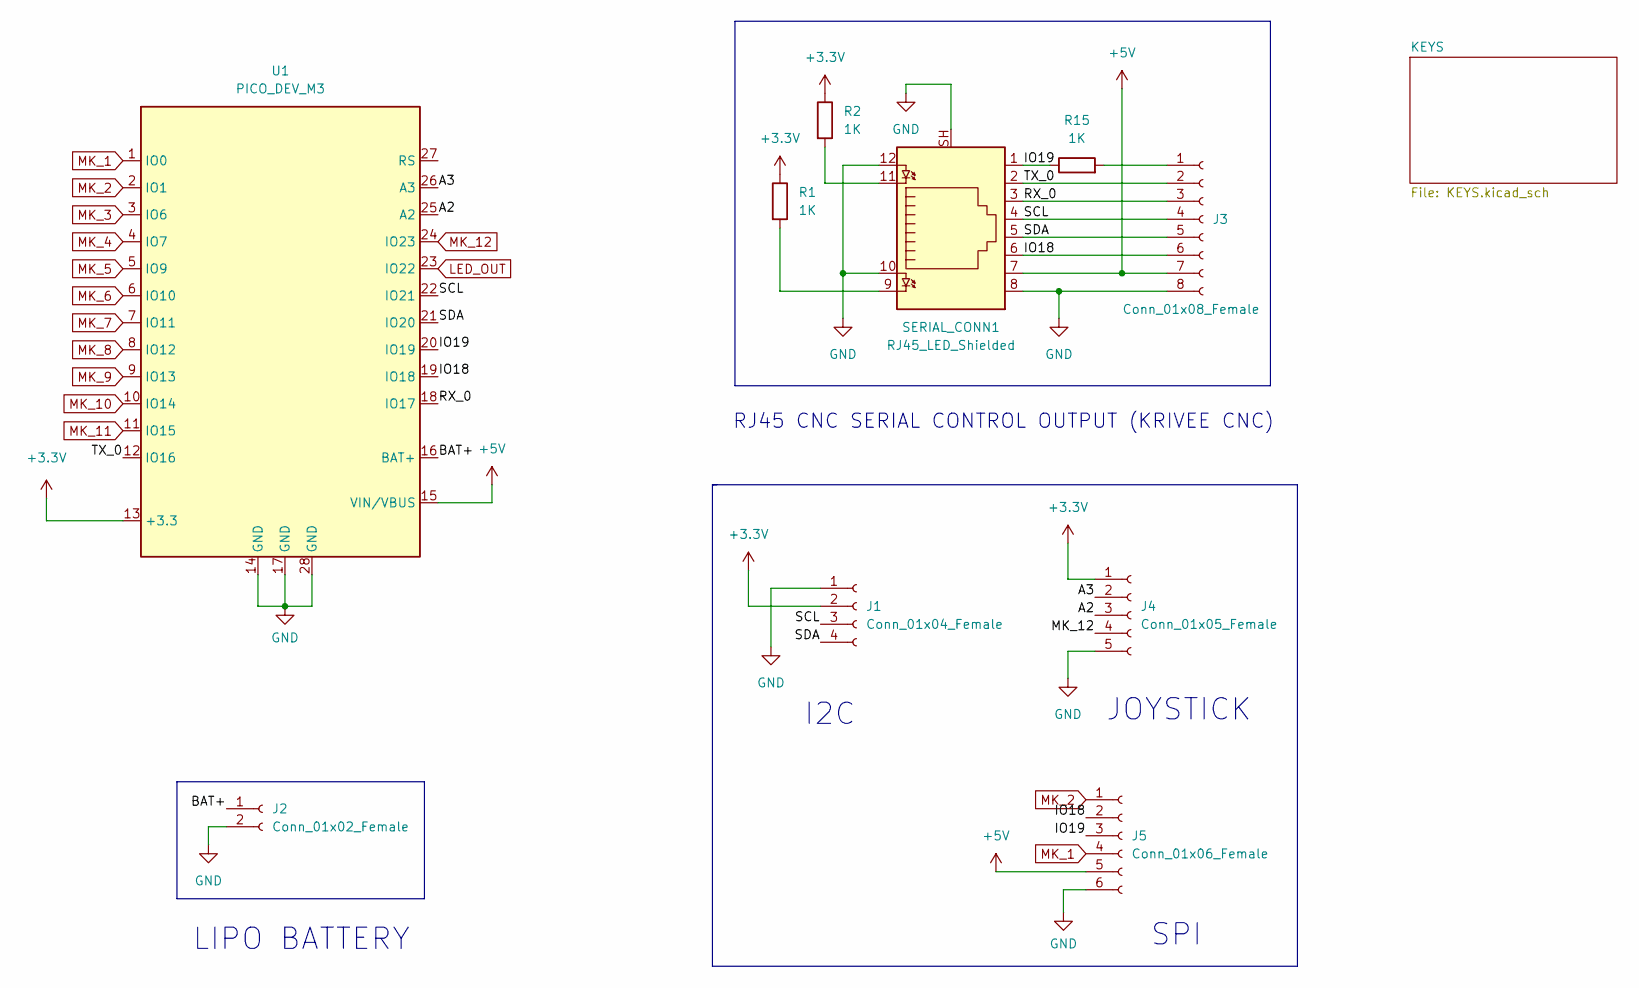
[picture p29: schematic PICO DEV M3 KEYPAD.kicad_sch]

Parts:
J1: Conn_01x04_Female; PinSocket_1x04_P2.54mm_Vertical
J2: Conn_01x02_Female; PinSocket_1x02_P2.54mm_Vertical
J3: Conn_01x08_Female; PinSocket_1x08_P2.54mm_Vertical
J4: Conn_01x05_Female; PinSocket_1x05_P2.54mm_Vertical
J5: Conn_01x06_Female; PinSocket_1x06_P2.54mm_Vertical
R1, R2, R15: 1K; R_0603_1608Metric
SERIAL_CONN1: RJ45_LED_Shielded; RJ45_LED_SHIELDED
U1: PICO_DEV_M3; PICO DEV M3

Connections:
+3.3V: J1.2, J4.1, R1.1, R2.1, U1.13 (+3.3); also elsewhere on the board
+5V: J3.7, J5.5, SERIAL_CONN1.7, U1.15 (VIN/VBUS)
/A2: J4.3, U1.25 (A2)
/A3: J4.2, U1.26 (A3)
/BAT+: J2.1, U1.16 (BAT+)
/IO18: J3.6, J5.2, SERIAL_CONN1.6, U1.19 (IO18)
/IO19: J5.3, R15.1, SERIAL_CONN1.1, U1.20 (IO19)
/RX_0: J3.3, SERIAL_CONN1.3, U1.18 (IO17)
/SCL: J1.3, J3.4, SERIAL_CONN1.4, U1.22 (IO21)
/SDA: J1.4, J3.5, SERIAL_CONN1.5, U1.21 (IO20)
/TX_0: J3.2, SERIAL_CONN1.2, U1.12 (IO16)
GND: J1.1, J2.2, J3.8, J4.5, J5.6, SERIAL_CONN1.8, SERIAL_CONN1.10, SERIAL_CONN1.12, SERIAL_CONN1.SH, U1.14 (GND), U1.17 (GND), U1.28 (GND); also elsewhere on the board
LED_OUT: U1.23 (IO22); also elsewhere on the board
MK_1: J5.4, U1.1 (IO0); also elsewhere on the board
MK_2: J5.1, U1.2 (IO1); also elsewhere on the board
MK_3: U1.3 (IO6); also elsewhere on the board
MK_4: U1.4 (IO7); also elsewhere on the board
MK_5: U1.5 (IO9); also elsewhere on the board
MK_6: U1.6 (IO10); also elsewhere on the board
MK_7: U1.7 (IO11); also elsewhere on the board
MK_8: U1.8 (IO12); also elsewhere on the board
MK_9: U1.9 (IO13); also elsewhere on the board
MK_10: U1.10 (IO14); also elsewhere on the board
MK_11: U1.11 (IO15); also elsewhere on the board
MK_12: J4.4, U1.24 (IO23); also elsewhere on the board
unnamed: J3.1, R15.2
unnamed: R1.2, SERIAL_CONN1.9
unnamed: R2.2, SERIAL_CONN1.11

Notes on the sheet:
LIPO BATTERY
JOYSTICK
RJ45 CNC SERIAL CONTROL OUTPUT (KRIVEE CNC)
I2C
SPI

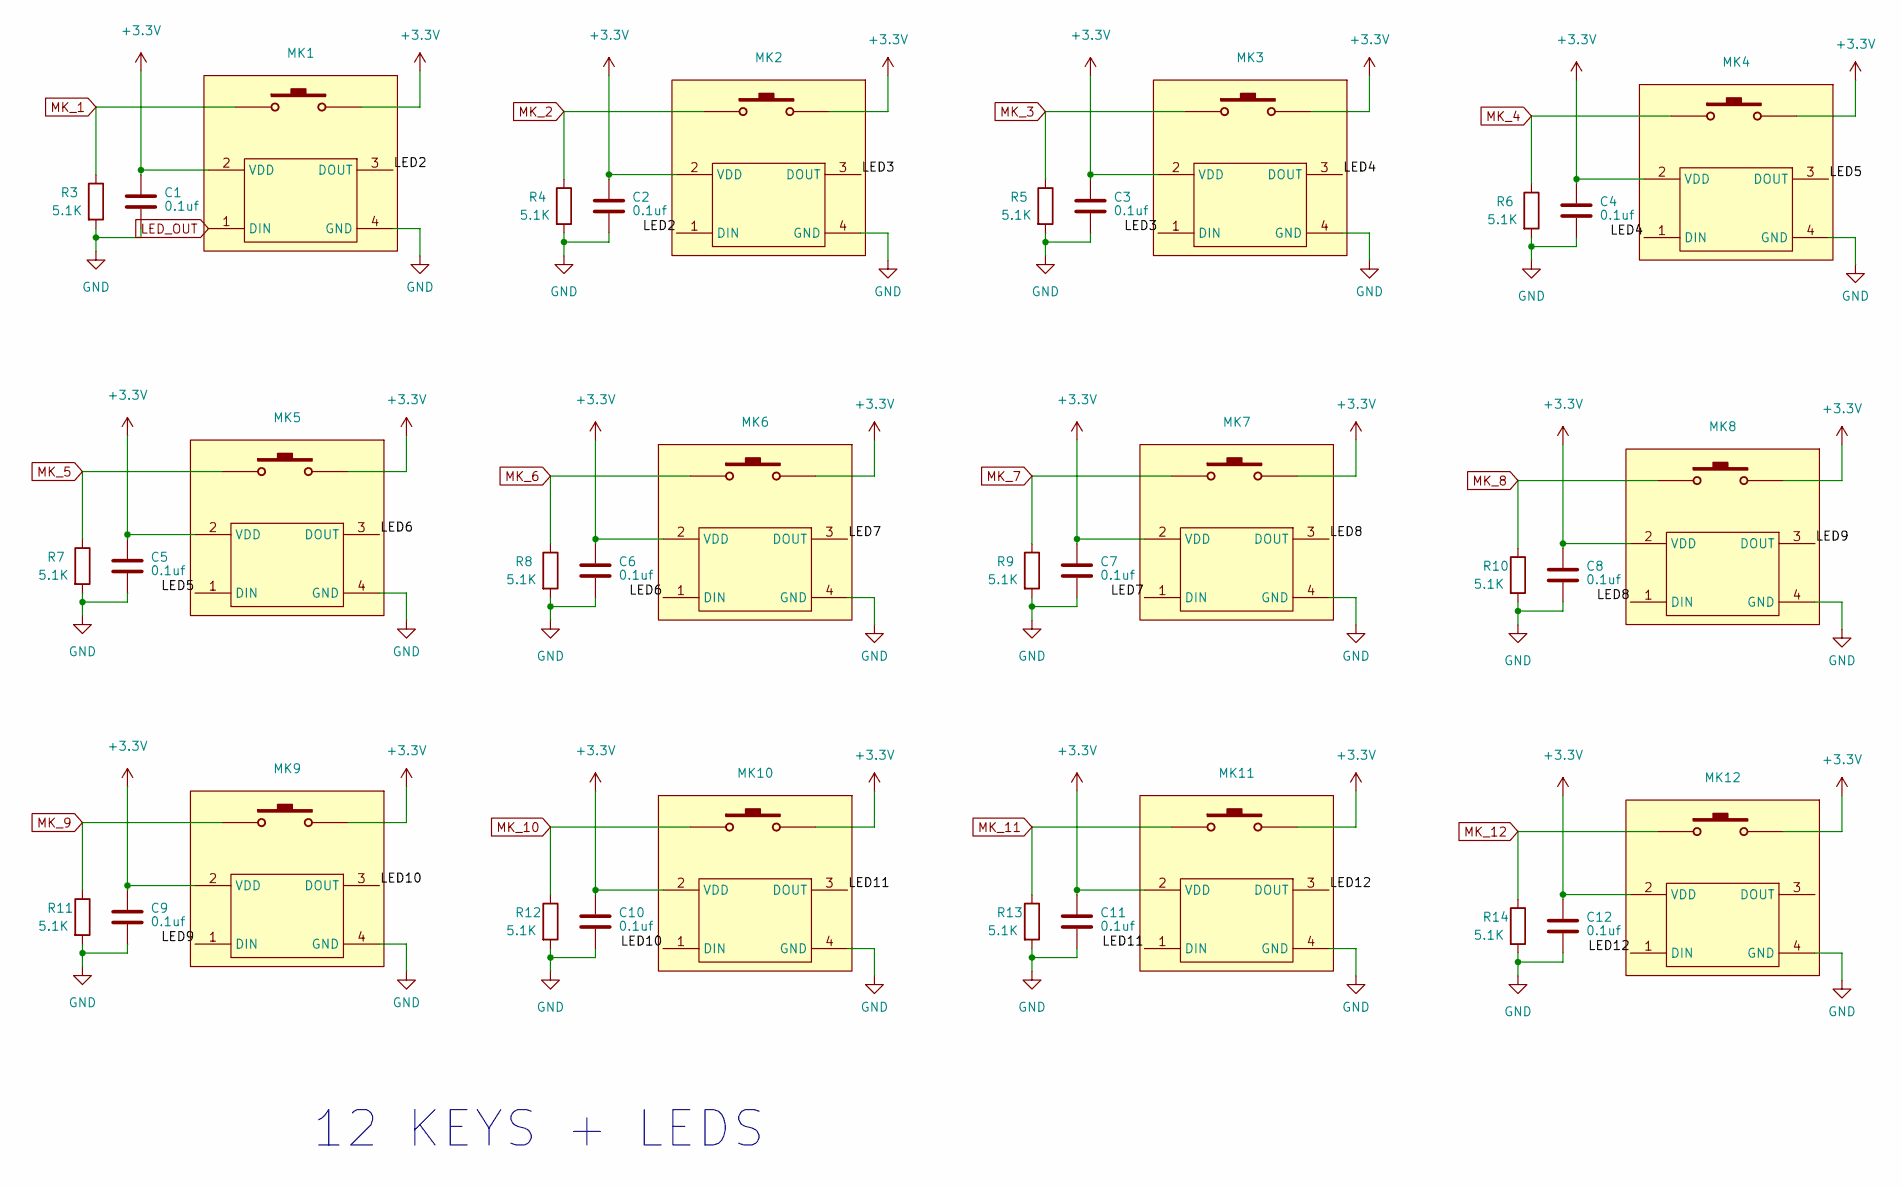
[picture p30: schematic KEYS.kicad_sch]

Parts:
C1, C2, C3, C4, C5, C6, C7, C8, C9, C10, C11, C12: 0.1uf; C_0603_1608Metric
MK1, MK2, MK3, MK4, MK5, MK6, MK7, MK8, MK9, MK10, MK11, MK12: Gateron_Switch; GATERON SWITCH
R3, R4, R5, R6, R7, R8, R9, R10, R11, R12, R13, R14: 5.1K; R_0603_1608Metric

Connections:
+3.3V: C1.1, C2.1, C3.1, C4.1, C5.1, C6.1, C7.1, C8.1, C9.1, C10.1, C11.1, C12.1, MK1.2 (VDD), MK1.6, MK2.2 (VDD), MK2.6, MK3.2 (VDD), MK3.6, MK4.2 (VDD), MK4.6, MK5.2 (VDD), MK5.6, MK6.2 (VDD), MK6.6, MK7.2 (VDD), MK7.6, MK8.2 (VDD), MK8.6, MK9.2 (VDD), MK9.6, MK10.2 (VDD), MK10.6, MK11.2 (VDD), MK11.6, MK12.2 (VDD), MK12.6; also elsewhere on the board
/KEYS/LED2: MK1.3 (DOUT), MK2.1 (DIN)
/KEYS/LED3: MK2.3 (DOUT), MK3.1 (DIN)
/KEYS/LED4: MK3.3 (DOUT), MK4.1 (DIN)
/KEYS/LED5: MK4.3 (DOUT), MK5.1 (DIN)
/KEYS/LED6: MK5.3 (DOUT), MK6.1 (DIN)
/KEYS/LED7: MK6.3 (DOUT), MK7.1 (DIN)
/KEYS/LED8: MK7.3 (DOUT), MK8.1 (DIN)
/KEYS/LED9: MK8.3 (DOUT), MK9.1 (DIN)
/KEYS/LED10: MK9.3 (DOUT), MK10.1 (DIN)
/KEYS/LED11: MK10.3 (DOUT), MK11.1 (DIN)
/KEYS/LED12: MK11.3 (DOUT), MK12.1 (DIN)
GND: C1.2, C2.2, C3.2, C4.2, C5.2, C6.2, C7.2, C8.2, C9.2, C10.2, C11.2, C12.2, MK1.4 (GND), MK2.4 (GND), MK3.4 (GND), MK4.4 (GND), MK5.4 (GND), MK6.4 (GND), MK7.4 (GND), MK8.4 (GND), MK9.4 (GND), MK10.4 (GND), MK11.4 (GND), MK12.4 (GND), R3.2, R4.2, R5.2, R6.2, R7.2, R8.2, R9.2, R10.2, R11.2, R12.2, R13.2, R14.2; also elsewhere on the board
LED_OUT: MK1.1 (DIN); also elsewhere on the board
MK_1: MK1.5, R3.1; also elsewhere on the board
MK_2: MK2.5, R4.1; also elsewhere on the board
MK_3: MK3.5, R5.1; also elsewhere on the board
MK_4: MK4.5, R6.1; also elsewhere on the board
MK_5: MK5.5, R7.1; also elsewhere on the board
MK_6: MK6.5, R8.1; also elsewhere on the board
MK_7: MK7.5, R9.1; also elsewhere on the board
MK_8: MK8.5, R10.1; also elsewhere on the board
MK_9: MK9.5, R11.1; also elsewhere on the board
MK_10: MK10.5, R12.1; also elsewhere on the board
MK_11: MK11.5, R13.1; also elsewhere on the board
MK_12: MK12.5, R14.1; also elsewhere on the board

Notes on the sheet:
12 KEYS + LEDS

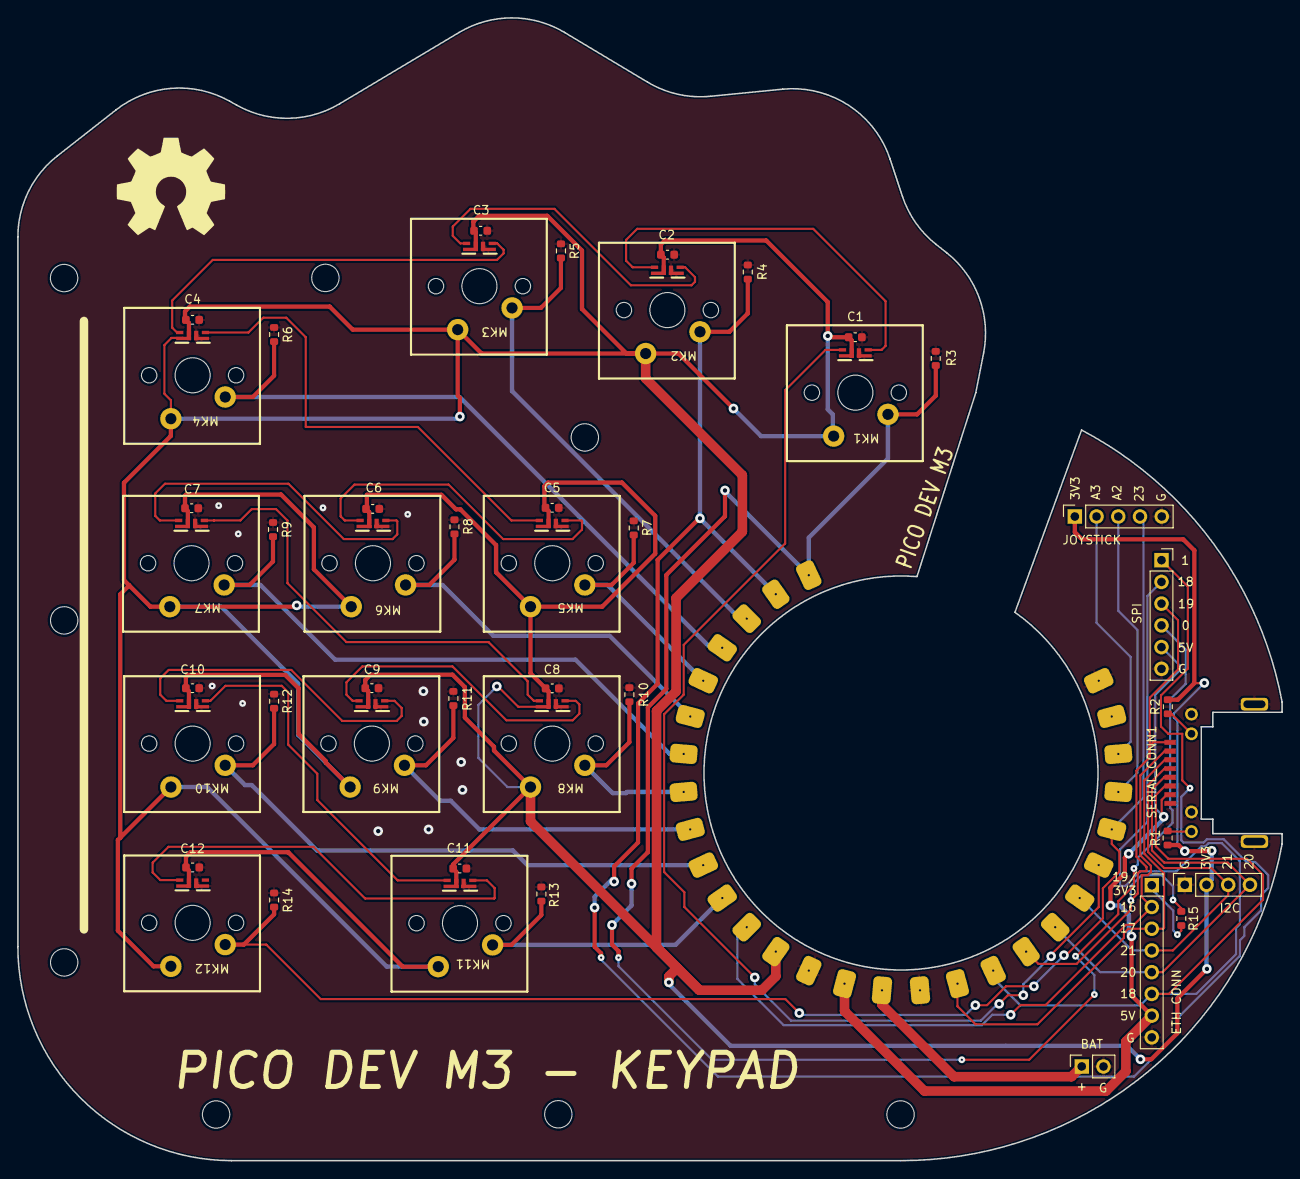
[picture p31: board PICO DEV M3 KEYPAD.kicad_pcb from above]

Board: 2 copper layers, 147.8 x 133.6 mm, 46 parts (0 on the bottom side), 39 nets.

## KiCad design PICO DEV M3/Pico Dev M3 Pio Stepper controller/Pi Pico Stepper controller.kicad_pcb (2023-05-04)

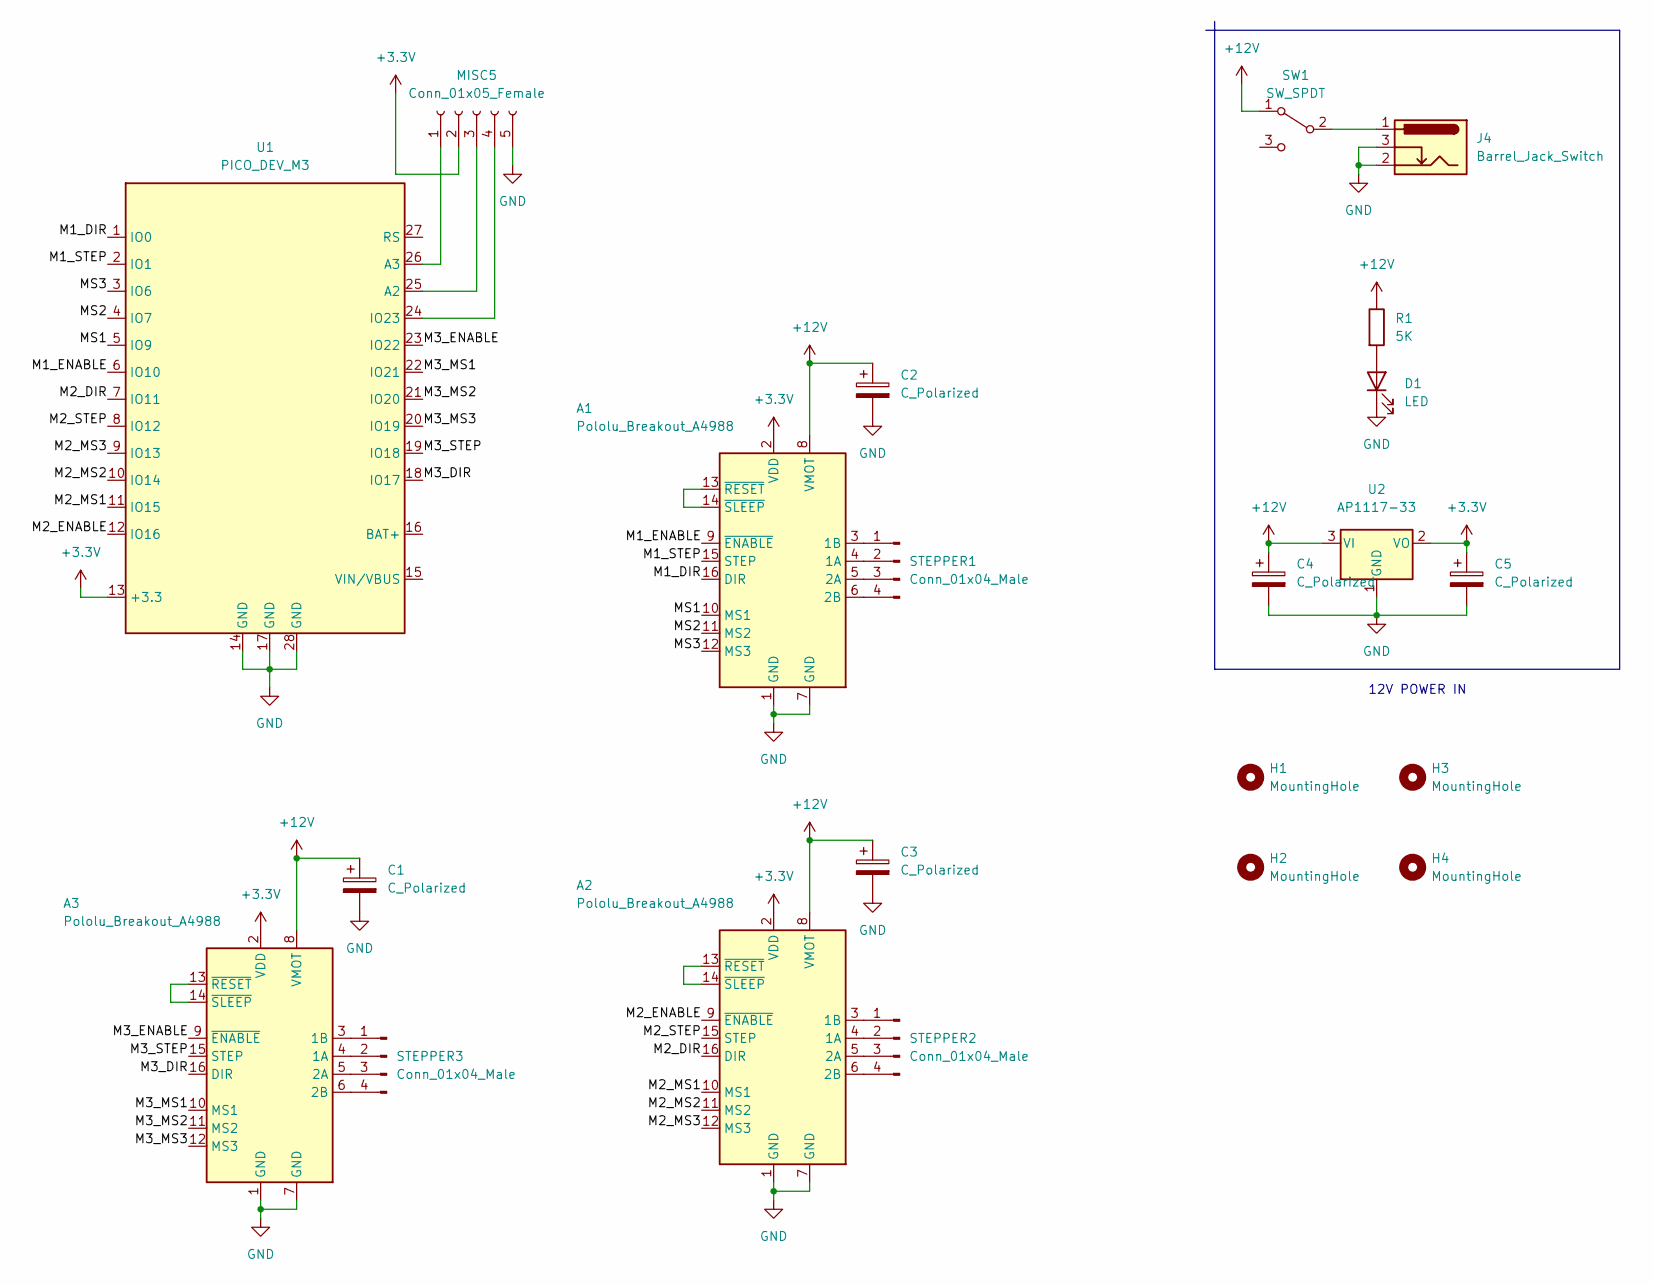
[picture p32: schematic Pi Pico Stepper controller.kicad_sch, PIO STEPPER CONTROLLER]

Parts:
A1, A2, A3: Pololu_Breakout_A4988; Pololu_Breakout-16_15.2x20.3mm
C1, C2, C3, C4, C5: C_Polarized; CP_Elec_4x5.4
D1: LED; LED_0603_1608Metric
H1, H2, H3, H4: MountingHole; MountingHole_2.2mm_M2
J4: Barrel_Jack_Switch; BarrelJack_Horizontal
MISC5: Conn_01x05_Female; PinSocket_1x05_P2.54mm_Vertical
R1: 5K; R_0603_1608Metric
STEPPER1, STEPPER2, STEPPER3: Conn_01x04_Male; PinHeader_1x04_P2.54mm_Vertical
SW1: SW_SPDT; SW_SPDT_PCM12
U1: PICO_DEV_M3; PICO DEV M3
U2: AP1117-33; SOT-223-3_TabPin2

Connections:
+3.3V: A1.2 (VDD), A2.2 (VDD), A3.2 (VDD), C5.1, MISC5.2, U1.13 (+3.3), U2.2 (VO)
+12V: A1.8 (VMOT), A2.8 (VMOT), A3.8 (VMOT), C1.1, C2.1, C3.1, C4.1, R1.1, SW1.1 (A), U2.3 (VI)
/M1_DIR: A1.16 (DIR), U1.1 (IO0)
/M1_ENABLE: A1.9 (~ENABLE), U1.6 (IO10)
/M1_STEP: A1.15 (STEP), U1.2 (IO1)
/M2_DIR: A2.16 (DIR), U1.7 (IO11)
/M2_ENABLE: A2.9 (~ENABLE), U1.12 (IO16)
/M2_MS1: A2.10 (MS1), U1.11 (IO15)
/M2_MS2: A2.11 (MS2), U1.10 (IO14)
/M2_MS3: A2.12 (MS3), U1.9 (IO13)
/M2_STEP: A2.15 (STEP), U1.8 (IO12)
/M3_DIR: A3.16 (DIR), U1.18 (IO17)
/M3_ENABLE: A3.9 (~ENABLE), U1.23 (IO22)
/M3_MS1: A3.10 (MS1), U1.22 (IO21)
/M3_MS2: A3.11 (MS2), U1.21 (IO20)
/M3_MS3: A3.12 (MS3), U1.20 (IO19)
/M3_STEP: A3.15 (STEP), U1.19 (IO18)
/MS1: A1.10 (MS1), U1.5 (IO9)
/MS2: A1.11 (MS2), U1.4 (IO7)
/MS3: A1.12 (MS3), U1.3 (IO6)
GND: A1.1 (GND), A1.7 (GND), A2.1 (GND), A2.7 (GND), A3.1 (GND), A3.7 (GND), C1.2, C2.2, C3.2, C4.2, C5.2, D1.1 (K), J4.2, J4.3, MISC5.5, U1.14 (GND), U1.17 (GND), U1.28 (GND), U2.1 (GND)
unnamed: A1.3 (1B), STEPPER1.1
unnamed: A1.4 (1A), STEPPER1.2
unnamed: A1.5 (2A), STEPPER1.3
unnamed: A1.6 (2B), STEPPER1.4
unnamed: A1.13 (~RESET), A1.14 (~SLEEP)
unnamed: A2.3 (1B), STEPPER2.1
unnamed: A2.4 (1A), STEPPER2.2
unnamed: A2.5 (2A), STEPPER2.3
unnamed: A2.6 (2B), STEPPER2.4
unnamed: A2.13 (~RESET), A2.14 (~SLEEP)
unnamed: A3.3 (1B), STEPPER3.1
unnamed: A3.4 (1A), STEPPER3.2
unnamed: A3.5 (2A), STEPPER3.3
unnamed: A3.6 (2B), STEPPER3.4
unnamed: A3.13 (~RESET), A3.14 (~SLEEP)
unnamed: D1.2 (A), R1.2
unnamed: J4.1, SW1.2 (B)
unnamed: MISC5.1, U1.26 (A3)
unnamed: MISC5.3, U1.25 (A2)
unnamed: MISC5.4, U1.24 (IO23)

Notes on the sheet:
12V POWER IN

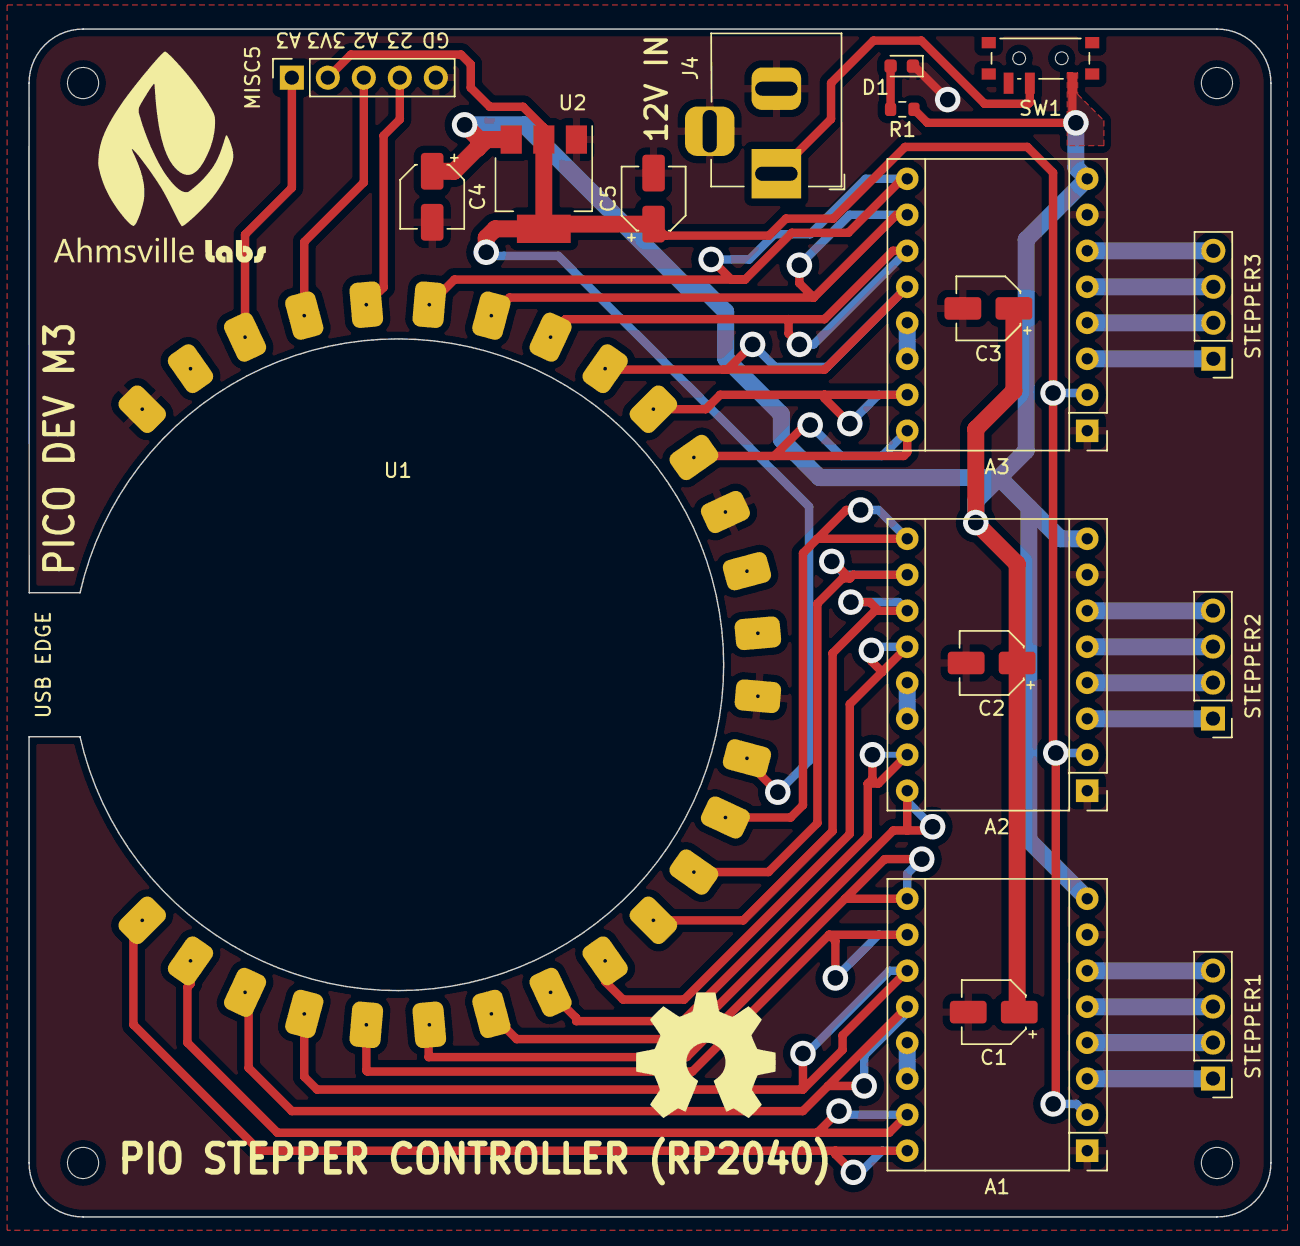
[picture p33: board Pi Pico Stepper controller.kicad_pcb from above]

Board: 2 copper layers, 87.6 x 83.8 mm, 22 parts (0 on the bottom side), 41 nets.

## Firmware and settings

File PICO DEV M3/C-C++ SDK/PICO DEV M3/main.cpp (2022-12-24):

#include <stdio.h>
#include "pico/stdlib.h"
#include "MagRotaryEncoding.h"
#include <string>
#include <string.h>
#include <iostream>
#include "hardware/adc.h"
#include "hardware/pwm.h"
#include "ws2812.pio.h"

using namespace std;

// #define ENCMODE 1 // BASE RESOLUTION ANALOG ONLY
#define ENCMODE 2 // BASE RESOLUTION ANALOG ONLY ABSOLUTE POSITIONING
// #define ENCMODE 3 // EXTENDED RESOLUTION ANALOG ONLY
// #define ENCMODE 4 // EXTENDED RESOLUTION ANALOG ONLY ABSOLUTE POSITIONING
// #define ENCMODE 5 // BASE RESOLUTION ANALOG AND DIGITAL
// #define ENCMODE 6 // BASE RESOLUTION ANALOG AND DIGITAL ABSOLUTE POSITIONING
// #define ENCMODE 7 // EXTENDED RESOLUTION ANALOG AND DIGITAL
// #define ENCMODE 8 // EXTENDED RESOLUTION ANALOG AND DIGITAL ABSOLUTE POSITIONING
// #define ENCMODE 9 // BASE RESOLUTION DIGITAL ONLY
// #define ENCMODE 10 // BASE RESOLUTION DIGITAL ONLY ABSOLUTE POSITIONING

/*************************digital pins******************************/
#define E1_INT1 2 // hall sensor 1 interrupt pin 1
#define E1_INT2 3 // hall sensor 1 interrupt pin 2
#define E2_INT1 4 // hall sensor 2 interrupt pin 1
#define E2_INT2 5 // hall sensor 2 interrupt pin 2

#define E1_ADC_PIN 26 // ADC PIN for hall sensor 1
#define E2_ADC_PIN 27 // ADC PIN for hall sensor 2

#define E1_ADC_CH 0 // rp2040 ADC ch 0 for E1
#define E2_ADC_CH 1 // rp2040 ADC ch 1 for E2

#define ENC_BASERES 36 // ENCODER BASE RESOLUTION

#define HAPTICS_PIN 25       // ENCODER HAPTICS PIN
#define HAPTICS_STRENGTH 255 // ENCODER HAPTICS PWM DUTY CYCLE
#define HAPTICS_DURATION 50  // ENCODER HAPTICS DURATION

#define ADC_RES 12                   // ADC RESOLUTION 10 OR 12 BITS
#define BOUND 20                     // ADC NOISE ALLOWANCE
#define EXTENDEDRESOLUTION_PERCENT 1 // PERCENTAGE OF FULL ITERPOLATED ENCODER RESOLUTION

#define CT1 24 // PUSH BUTTON (CT1)

#define NUM_LEDS 18 // Num of leds on board
const int ALED_PIN = 8;

float ALEDBrightness = 0.2;
uint32_t ledMem[18];

#define HIGHLEVEL 0x02
#define LOWLEVEL 0x01
#define RISING 0x08
#define FALLING 0x04

#define red 1
#define green 2
#define blue 3

int retstep1 = 0;
int retstep2 = 0;
bool debug = true;
long debugtimetracker = 0;
int count = 0;
int prevcount = 0;
float G_setpoint = 0;

#if ENCMODE == 1
MagRotaryEncoder myKnob = MagRotaryEncoder(E1_ADC_PIN, E1_ADC_CH, E2_ADC_PIN, E2_ADC_CH);
#elif ENCMODE == 5 || ENCMODE == 6 || ENCMODE == 7 || ENCMODE == 8
MagRotaryEncoder myKnob = MagRotaryEncoder(E1_ADC_PIN, E1_ADC_CH, E2_ADC_PIN, E2_ADC_CH, E1_INT1, E2_INT1);
#else
MagRotaryEncoder myKnob = MagRotaryEncoder(E1_ADC_PIN, E1_ADC_CH, E2_ADC_PIN, E2_ADC_CH);
#endif

//;

char inbuff[100];
int buffloatcounter = 0;
bool dataavailable = false;
string inString = "";
string outstr = "";

int activeledcolor[NUM_LEDS];

volatile int activesensor1Interrupt = 1; // used for switching active ISR
volatile int count_interrupt = 0;

static inline void put_pixel(uint32_t pixel_grb)
{
  pio_sm_put_blocking(pio0, 0, pixel_grb << 8u);
}

static inline uint32_t urgb_u32(uint8_t r, uint8_t g, uint8_t b)
{
  return ((uint32_t)(r) << 8) |
         ((uint32_t)(g) << 16) |
         (uint32_t)(b);
}

#if ENCMODE == 5 || ENCMODE == 6 || ENCMODE == 7 || ENCMODE == 8
void mainISR(uint gpiopin, uint32_t events) // ENCODER 1 INT 1 (SOUTH)
{
  myKnob.singleSensor_INT(gpiopin);
}
void setinterrupt()
{
  int pinNum = myKnob.get_sensorINTpin(1);
  gpio_set_irq_enabled_with_callback(pinNum, RISING, true, mainISR);
  pinNum = myKnob.get_sensorINTpin(2);
  gpio_set_irq_enabled_with_callback(pinNum, RISING, true, mainISR);
}

#elif ENCMODE == 9 || ENCMODE == 10
void mainISR(uint gpiopin, uint32_t events) // ENCODER 1 INT 1 (SOUTH)
{
  /************************servo encoder*********************************/
  if (gpiopin == myKnob.get_sensorINTpin(3))
  {
    // 3
    activesensor1Interrupt = myKnob.processExINT(3);
    // printf("3");
  }
  else if (gpiopin == myKnob.get_sensorINTpin(1))
  {
    // 1
    activesensor1Interrupt = myKnob.processExINT(1);
    // printf("1");
  }

  if (gpiopin == myKnob.get_sensorINTpin(2))
  {
    // 2
    activesensor1Interrupt = myKnob.processExINT(2);
    // printf("2");
  }
  else if (gpiopin == myKnob.get_sensorINTpin(4))
  {
    // 4
    activesensor1Interrupt = myKnob.processExINT(4);
    // printf("4");
  }
  /***********************************************************************/

  /***************************knob encoder********************************/
  if (gpiopin == myKnob.get_sensorINTpin(3))
  {
    // 3
    myKnob.processExINT(3);
    // printf("3");
  }
  else if (gpiopin == myKnob.get_sensorINTpin(1))
  {
    // 1
    myKnob.processExINT(1);
    // printf("1");
  }

  if (gpiopin == myKnob.get_sensorINTpin(2))
  {
    // 2
    myKnob.processExINT(2);
    // printf("2");
  }
  else if (gpiopin == myKnob.get_sensorINTpin(4))
  {
    // 4
    myKnob.processExINT(4);
    // printf("4");
  }
  /***************************************************************************/
}

void setinterrupt()
{
  myKnob.setExclINTmode(E1_INT1, E1_INT2, E2_INT1, E2_INT2, true);

  int pinNum = myKnob.get_sensorINTpin(1);
  gpio_set_irq_enabled_with_callback(pinNum, RISING, true, mainISR);
  pinNum = myKnob.get_sensorINTpin(2);
  gpio_set_irq_enabled_with_callback(pinNum, RISING, true, mainISR);
  pinNum = myKnob.get_sensorINTpin(3);
  gpio_set_irq_enabled_with_callback(pinNum, RISING, true, mainISR);
  pinNum = myKnob.get_sensorINTpin(4);
  gpio_set_irq_enabled_with_callback(pinNum, RISING, true, mainISR);
}

#endif

int activeledindex = 0;
int setLedBrightness(int clevel)
{
  float tempb = float(clevel) * ALEDBrightness;
  return int(tempb);
}
void updateLed(uint8_t r, uint8_t g, uint8_t b, int ledindex)
{
  for (size_t i = 0; i < NUM_LEDS; i++)
  {
    if (i == ledindex)
    {
      ledMem[i] = urgb_u32(setLedBrightness(r), setLedBrightness(g), setLedBrightness(b));
      put_pixel(ledMem[i]);
    }
    else
    {
      put_pixel(ledMem[i]);
    }
  }
  sleep_us(110);
}

void caliberateSensors()
{
  int res1 = myKnob.CalibrateSensors(1);
  int res2 = myKnob.CalibrateSensors(2);

  myKnob.LoadCalibrationData(res1, res2);
  printf("sensor 1 center >> %d sensor 2 center >> %d \n", res1, res2);
}

void readtobuffer()
{
  char chr = getchar_timeout_us(0);
  if (chr != 255)
  {
    if (chr == '*')
    {
      dataavailable = true;
    }
    // cout << chr << buffloatcounter << std::endl;
    if (buffloatcounter < sizeof(inbuff))
    {
      inbuff[buffloatcounter] = chr;
      buffloatcounter += 1;
    }
    else
    {
      buffloatcounter = 0;
    }
  }
  else
  {
    dataavailable = false;
  }
}

void processinData()
{
  if (dataavailable)
  {
    // cout << inbuff << std::endl;
    int tempcnt = 0;
    while (inbuff[tempcnt] != '*')
    {
      inString += inbuff[tempcnt];
      tempcnt += 1;
    }
    printf(inString.c_str());
    printf("\n");
    // quick serial commands
    if (inString.find("hres=") == 0) // set high res encoding resolution
    {
      inString.replace(inString.find("hres="), 5, "");
      printf("setting high res encoding resolution to >> %s \n", inString.c_str());
      myKnob.set_resolution(stoi(inString));
    }
    if (inString.find("b=") == 0) // set sensor value bound
    {
      inString.replace(inString.find("b="), 2, "");
      printf("setting BOUND to >> %s \n", inString.c_str());
      myKnob.set_bound(stoi(inString));
    }
    if (inString.find("b?") == 0) // get ideal bound (b?=1)
    {
      inString.replace(inString.find("b?"), 2, "");
      myKnob.get_bound(stoi(inString));
    }
    if (inString.find("st") == 0) // get ideal bound (b?=1)
    {
      printf("setting current position as encoder start position \n");
      printf("start position set to >> %d \n", myKnob.setToStart());
    }
    if (inString.find("debug") == 0) // get ideal bound (b?=1)
    {
      if (debug)
      {
        debug = false;
        printf("debug info turned off\n");
      }
      else
      {
        debug = true;
        printf("debug info turned on\n");
      }
    }
    if (inString.find("cali") == 0) // get ideal bound (b?=1)
    {
      printf("Make sure the knob is not attached for this process.... \n");
      printf("calibrating encoder.... \n");
      caliberateSensors();
    }

    buffloatcounter = 0;
    dataavailable = false;
    memset(inbuff, 0, sizeof(inbuff));
    inString = "";
  }
}

/*****************************************************************************/

long infotimer = (time_us_64() / 1000);
float floatcount = 0;
void updateCount()
{
#if ENCMODE == 2 || ENCMODE == 6 || ENCMODE == 10
  retstep1 = myKnob.detect_rotation(); // function returns a signed integer based on rotation step detected
  if (retstep1 != 0)
  {
    count = retstep1;
    printf("COUNT >> %d \n", count);
  }
#elif ENCMODE == 3 || ENCMODE == 7
  floatcount += myKnob.detect_rotationHR(); // function returns a signed integer based on rotation step detected
  if (int(floatcount) != count)
  {
    if (((time_us_64() / 1000) - infotimer) > 5)
    {
      printf("FLOATCOUNT >> %f \n", floatcount);
      infotimer = (time_us_64() / 1000);
    }
    count = int(floatcount);
  }

#elif ENCMODE == 4 || ENCMODE == 8
  floatcount = myKnob.detect_rotationHR(); // function returns a signed integer based on rotation step detected
  if (((time_us_64() / 1000) - infotimer) > 50)
  {
    printf("FLOATCOUNT >> %f \n", floatcount);
    infotimer = (time_us_64() / 1000);
  }
  count = int(floatcount);
#else
  retstep1 = myKnob.detect_rotation(); // function returns a signed integer based on rotation step detected
  if (retstep1 != 0)
  {
    count += retstep1;
    printf("COUNT >> %d \n", count);
  }

#endif
  
}

int main()
{

  stdio_init_all();
  sleep_ms(500);

  const uint LED_PIN = PICO_DEFAULT_LED_PIN;
  gpio_init(LED_PIN);
  gpio_set_dir(LED_PIN, GPIO_OUT);

  gpio_init(CT1);
  gpio_set_dir(CT1, GPIO_IN);
  gpio_pull_up(CT1);

  PIO pio = pio0;
  int sm = 0;
  uint offset = pio_add_program(pio, &ws2812_program);
  // char str[12];

  ws2812_program_init(pio, sm, offset, ALED_PIN, 800000, false);

  for (size_t i = 0; i < NUM_LEDS; i++)
  {
    updateLed(255, 0, 0, i);
  }
  sleep_ms(1000);
  for (size_t i = 0; i < NUM_LEDS; i++)
  {
    updateLed(0, 255, 0, i);
  }
  sleep_ms(1000);
  for (size_t i = 0; i < NUM_LEDS; i++)
  {
    updateLed(0, 0, 255, i);
  }
  sleep_ms(1000);

#if ENCMODE == 1
  myKnob.set_haptics(HAPTICS_PIN, HAPTICS_DURATION, HAPTICS_STRENGTH); // set haptic feedback variables (arduino pwm pin, duration of haptics(ms), pwn strength from 0-255)
  myKnob.set_adcresolution(ADC_RES);
  myKnob.set_bound(BOUND);
  myKnob.initialize_encoder();
  myKnob.detect_rotationWithRate(true);
#elif ENCMODE == 2
  myKnob.set_haptics(HAPTICS_PIN, HAPTICS_DURATION, HAPTICS_STRENGTH); // set haptic feedback variables (arduino pwm pin, duration of haptics(ms), pwn strength from 0-255)
  myKnob.set_adcresolution(ADC_RES);
  myKnob.set_bound(BOUND);
  myKnob.set_encoderResolution(ENC_BASERES);
  myKnob.initialize_encoder();
  myKnob.invertCount(true);
  myKnob.setToStart();
#elif ENCMODE == 3
  myKnob.set_haptics(HAPTICS_PIN, HAPTICS_DURATION, HAPTICS_STRENGTH); // set haptic feedback variables (arduino pwm pin, duration of haptics(ms), pwn strength from 0-255)
  myKnob.set_adcresolution(ADC_RES);
  myKnob.setExtendedAbsolutePositioning(false);
  myKnob.set_resolution(EXTENDEDRESOLUTION_PERCENT);
  myKnob.set_encoderResolution(ENC_BASERES);
  myKnob.set_bound(BOUND);
  myKnob.initialize_encoder();
  // myKnob.setToStart();
#elif ENCMODE == 4
  myKnob.set_haptics(HAPTICS_PIN, HAPTICS_DURATION, HAPTICS_STRENGTH); // set haptic feedback variables (arduino pwm pin, duration of haptics(ms), pwn strength from 0-255)
  myKnob.set_adcresolution(ADC_RES);
  myKnob.setExtendedAbsolutePositioning(true);
  myKnob.set_resolution(EXTENDEDRESOLUTION_PERCENT);
  myKnob.set_encoderResolution(ENC_BASERES);
  myKnob.set_bound(BOUND);
  myKnob.initialize_encoder();
  myKnob.setToStart();
#elif ENCMODE == 5
  setinterrupt();
  myKnob.set_haptics(HAPTICS_PIN, HAPTICS_DURATION, HAPTICS_STRENGTH); // set haptic feedback variables (arduino pwm pin, duration of haptics(ms), pwn strength from 0-255)
  myKnob.set_adcresolution(ADC_RES);
  myKnob.set_bound(BOUND);
  myKnob.initialize_encoder();
#elif ENCMODE == 6
  setinterrupt();
  myKnob.set_haptics(HAPTICS_PIN, HAPTICS_DURATION, HAPTICS_STRENGTH); // set haptic feedback variables (arduino pwm pin, duration of haptics(ms), pwn strength from 0-255)
  myKnob.set_adcresolution(ADC_RES);
  myKnob.set_bound(BOUND);
  myKnob.set_encoderResolution(ENC_BASERES);
  myKnob.initialize_encoder();
  // myKnob.invertCount(true);
  myKnob.setToStart();
#elif ENCMODE == 7
  setinterrupt();
  myKnob.set_haptics(HAPTICS_PIN, HAPTICS_DURATION, HAPTICS_STRENGTH); // set haptic feedback variables (arduino pwm pin, duration of haptics(ms), pwn strength from 0-255)
  myKnob.set_adcresolution(ADC_RES);
  myKnob.setExtendedAbsolutePositioning(false);
  myKnob.set_resolution(EXTENDEDRESOLUTION_PERCENT);
  myKnob.set_encoderResolution(ENC_BASERES);
  myKnob.set_bound(BOUND);
  myKnob.initialize_encoder();
#elif ENCMODE == 8
  setinterrupt();
  myKnob.set_haptics(HAPTICS_PIN, HAPTICS_DURATION, HAPTICS_STRENGTH); // set haptic feedback variables (arduino pwm pin, duration of haptics(ms), pwn strength from 0-255)
  myKnob.set_adcresolution(ADC_RES);
  myKnob.setExtendedAbsolutePositioning(true);
  myKnob.set_resolution(EXTENDEDRESOLUTION_PERCENT);
  myKnob.set_encoderResolution(ENC_BASERES);
  myKnob.set_bound(BOUND);
  myKnob.initialize_encoder();
  myKnob.setToStart();
#elif ENCMODE == 9
  setinterrupt();
  myKnob.set_haptics(HAPTICS_PIN, HAPTICS_DURATION, HAPTICS_STRENGTH); // set haptic feedback variables (arduino pwm pin, duration of haptics(ms), pwn strength from 0-255)
  myKnob.set_haptics(HAPTICS_PIN, HAPTICS_DURATION, HAPTICS_STRENGTH);
  myKnob.initialize_encoder();
  myKnob.initialize_encoder();
#elif ENCMODE == 10
  setinterrupt();
  myKnob.set_haptics(HAPTICS_PIN, HAPTICS_DURATION, HAPTICS_STRENGTH); // set haptic feedback variables (arduino pwm pin, duration of haptics(ms), pwn strength from 0-255)
  myKnob.set_encoderResolution(ENC_BASERES);
  myKnob.initialize_encoder();
  // myKnob.invertCount(true);
  myKnob.setToStart();
#endif

  while (true)
  {

    if (debug)
    {
      if (((time_us_64() / 1000) - debugtimetracker) > 1000)
      {
        myKnob.DebugEncoder();
        debugtimetracker = (time_us_64() / 1000);
      }
    }

    if (gpio_get(CT1) == 0)
    {
      printf("button pressed \n");
      myKnob.setToStart();
    }

    readtobuffer();
    processinData();
    updateCount();

    if (count > prevcount) //++
    {
      if (activeledindex == (NUM_LEDS - 1))
      {
        activeledindex = 0;
      }
      else
      {
        activeledindex += 1;
      }
      for (size_t i = 0; i < NUM_LEDS; i++)
      {
        ledMem[i] = 0;
      }
      
      updateLed(255, 0, 0, activeledindex);
      prevcount = count;
    }
    else if (count < prevcount) //--
    {
      if (activeledindex == (0))
      {
        activeledindex = NUM_LEDS - 1;
      }
      else
      {
        activeledindex -= 1;
      }
      for (size_t i = 0; i < NUM_LEDS; i++)
      {
        ledMem[i] = 0;
      }
      updateLed(255, 0, 0, activeledindex);
      prevcount = count;
    }
  }
}

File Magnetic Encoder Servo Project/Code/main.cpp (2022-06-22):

#include <stdio.h>
#include "pico/stdlib.h"
#include "MagRotaryEncoding.h"
#include <string>
#include <string.h>
#include <iostream>
#include "hardware/adc.h"
#include "hardware/pwm.h"
#include "ws2812.pio.h"
#include "PID.h"

using namespace std;

//#define ENCMODE 1 // BASE RESOLUTION ANALOG ONLY
//#define ENCMODE 2 // BASE RESOLUTION ANALOG ONLY ABSOLUTE POSITIONING
//#define ENCMODE 3 // EXTENDED RESOLUTION ANALOG ONLY
//#define ENCMODE 4 // BASE RESOLUTION ANALOG AND DIGITAL
//#define ENCMODE 5 // BASE RESOLUTION ANALOG AND DIGITAL ABSOLUTE POSITIONING
//#define ENCMODE 6 // EXTENDED RESOLUTION ANALOG AND DIGITAL
#define ENCMODE 7 // BASE RESOLUTION DIGITAL ONLY
//#define ENCMODE 8 // BASE RESOLUTION DIGITAL ONLY ABSOLUTE POSITIONING

/*************************servo encoder******************************/
#define E1_INT1 16 // hall sensor 1 interrupt pin 1
#define E1_INT2 17 // hall sensor 1 interrupt pin 2
#define E2_INT1 18 // hall sensor 2 interrupt pin 1
#define E2_INT2 19 // hall sensor 2 interrupt pin 2

/************************controller encoder*************************/
#define CON_E1_INT1 4 // hall sensor 1 interrupt pin 1
#define CON_E1_INT2 5 // hall sensor 1 interrupt pin 2
#define CON_E2_INT1 6 // hall sensor 2 interrupt pin 1
#define CON_E2_INT2 7 // hall sensor 2 interrupt pin 2

#define E1_ADC_PIN 26 // ADC PIN for hall sensor 1
#define E2_ADC_PIN 27 // ADC PIN for hall sensor 2

#define E1_ADC_CH 0 // rp2040 ADC ch 0 for E1
#define E2_ADC_CH 1 // rp2040 ADC ch 1 for E2

#define ENC_BASERES 60 // ENCODER BASE RESOLUTION

#define HAPTICS_PIN 25       // ENCODER HAPTICS PIN
#define HAPTICS_STRENGTH 255 // ENCODER HAPTICS PWM DUTY CYCLE
#define HAPTICS_DURATION 50  // ENCODER HAPTICS DURATION

#define ADC_RES 12                    // ADC RESOLUTION 10 OR 12 BITS
#define BOUND 20                      // ADC NOISE ALLOWANCE
#define EXTENDEDRESOLUTION_PERCENT 95 // PERCENTAGE OF FULL ITERPOLATED ENCODER RESOLUTION

#define CT1 8 // PUSH BUTTON (CT1)

#define NUM_LEDS 15 // Num of leds on board
const int ALED_PIN = 15;

#define revMotor 13
#define forMotor 12

void setpwmpins()
{
  gpio_set_function(forMotor, GPIO_FUNC_PWM);
  gpio_set_function(revMotor, GPIO_FUNC_PWM);
  uint slice_num = pwm_gpio_to_slice_num(forMotor);
  // Set period of 4 cycles (0 to 3 inclusive)
  pwm_config config = pwm_get_default_config();
  pwm_config_set_clkdiv(&config, 4.f);
  pwm_init(slice_num, &config, true);
  pwm_set_wrap(slice_num, 255);
  // Set channel A output high for one cycle before dropping
  // pwm_set_chan_level(slice_num, pwm_gpio_to_channel(forMotor), 0);
  // Set the PWM running
  pwm_set_enabled(slice_num, true);

  slice_num = pwm_gpio_to_slice_num(revMotor);
  // // Set period of 4 cycles (0 to 3 inclusive)
  pwm_init(slice_num, &config, true);
  pwm_set_wrap(slice_num, 255);
   pwm_set_wrap(slice_num, 255);
  // // Set channel A output high for one cycle before dropping
  // pwm_set_chan_level(slice_num, pwm_gpio_to_channel(revMotor), 0);
  // // Set the PWM running
  pwm_set_enabled(slice_num, true);
}
void PWM_On(int strn, int pinnum)
{
  if (pinnum == forMotor)
  {
    pwm_set_gpio_level(revMotor, 0);
  }
  else if (pinnum == revMotor)
  {
    pwm_set_gpio_level(forMotor, 0);
  }

  pwm_set_gpio_level(pinnum, strn);
}

#define HIGHLEVEL 0x02
#define LOWLEVEL 0x01
#define RISING 0x08
#define FALLING 0x04

#define red 1
#define green 2
#define blue 3

int retstep1 = 0;
int retstep2 = 0;
bool debug = false;
int count = 0;
int prevcount = 0;
float G_setpoint = 0;

#if ENCMODE == 1
MagRotaryEncoder servoEncoder = MagRotaryEncoder(E1_ADC_PIN, E1_ADC_CH, E2_ADC_PIN, E2_ADC_CH);
#elif ENCMODE == 4 || ENCMODE == 5 || ENCMODE == 6
MagRotaryEncoder servoEncoder = MagRotaryEncoder(E1_ADC_PIN, E1_ADC_CH, E2_ADC_PIN, E2_ADC_CH, E1_INT1, E2_INT1);
#else
MagRotaryEncoder servoEncoder = MagRotaryEncoder(E1_ADC_PIN, E1_ADC_CH, E2_ADC_PIN, E2_ADC_CH);
MagRotaryEncoder myKnob = MagRotaryEncoder(E1_ADC_PIN, E1_ADC_CH, E2_ADC_PIN, E2_ADC_CH);
#endif

//;

char inbuff[100];
int buffcounter = 0;
bool dataavailable = false;
string inString = "";
string outstr = "";

int activeledcolor[NUM_LEDS];

volatile int activesensor1Interrupt = 1; // used for switching active ISR
volatile int count_interrupt = 0;

static inline void put_pixel(uint32_t pixel_grb)
{
  pio_sm_put_blocking(pio0, 0, pixel_grb << 8u);
}

static inline uint32_t urgb_u32(uint8_t r, uint8_t g, uint8_t b)
{
  return ((uint32_t)(r) << 8) |
         ((uint32_t)(g) << 16) |
         (uint32_t)(b);
}

#if ENCMODE == 4 || ENCMODE == 5 || ENCMODE == 6
void mainISR(uint gpiopin, uint32_t events) // ENCODER 1 INT 1 (SOUTH)
{
  servoEncoder.singleSensor_INT(gpiopin);
}
void setinterrupt()
{
  int pinNum = servoEncoder.get_sensorINTpin(1);
  gpio_set_irq_enabled_with_callback(pinNum, RISING, true, mainISR);
  pinNum = servoEncoder.get_sensorINTpin(2);
  gpio_set_irq_enabled_with_callback(pinNum, RISING, true, mainISR);
}

#elif ENCMODE == 7 || ENCMODE == 8
void mainISR(uint gpiopin, uint32_t events) // ENCODER 1 INT 1 (SOUTH)
{
/************************servo encoder*********************************/
  if (gpiopin == servoEncoder.get_sensorINTpin(3))
  {
    // 3
    activesensor1Interrupt = servoEncoder.processExINT(3);
    // printf("3");
  }
  else if (gpiopin == servoEncoder.get_sensorINTpin(1))
  {
    // 1
    activesensor1Interrupt = servoEncoder.processExINT(1);
    // printf("1");
  }

  if (gpiopin == servoEncoder.get_sensorINTpin(2))
  {
    // 2
    activesensor1Interrupt = servoEncoder.processExINT(2);
    // printf("2");
  }
  else if (gpiopin == servoEncoder.get_sensorINTpin(4))
  {
    // 4
    activesensor1Interrupt = servoEncoder.processExINT(4);
    // printf("4");
  }
/***********************************************************************/

/***************************knob encoder********************************/
if (gpiopin == myKnob.get_sensorINTpin(3))
  {
    // 3
    myKnob.processExINT(3);
    // printf("3");
  }
  else if (gpiopin == myKnob.get_sensorINTpin(1))
  {
    // 1
     myKnob.processExINT(1);
    // printf("1");
  }

  if (gpiopin == myKnob.get_sensorINTpin(2))
  {
    // 2
    myKnob.processExINT(2);
    // printf("2");
  }
  else if (gpiopin == myKnob.get_sensorINTpin(4))
  {
    // 4
     myKnob.processExINT(4);
    // printf("4");
  }
  /***************************************************************************/

}
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

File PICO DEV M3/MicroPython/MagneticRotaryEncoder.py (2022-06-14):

from machine import Pin, ADC, PWM, Timer
import time


class MagRotaryEncoder:

    # self.sensor1_pin,self.sensor2_pin,s1dpin1,s1dpin2,s2dpin1,s2dpin2 = ADC(Pin(0)),ADC(Pin(0)),Pin(0, Pin.IN, Pin.PULL_UP),Pin(0, Pin.IN, Pin.PULL_UP),Pin(0, Pin.IN, Pin.PULL_UP),Pin(0, Pin.IN, Pin.PULL_UP)
    isr1, isr2, isr3, isr4 = 0, 0, 0, 0
    testcount = 0
    s1INTswitch, s2INTswitch = True, True
    opargs = [[0, 0], [0, 0]]
    startposition = 0
    sensor1_pin, sensor2_pin, useInterrupt, exclInterrupt = ADC(0), ADC(1), False, False
    SensorINTpin = [Pin(0, Pin.IN, Pin.PULL_UP),Pin(0, Pin.IN, Pin.PULL_UP),Pin(0, Pin.IN, Pin.PULL_UP),Pin(0, Pin.IN, Pin.PULL_UP)]
    SensorINTactualpin = [0,0,0,0]
    bound = 3000
    S1_Neutral, S2_Neutral, Neutral = [
        0, 0], [0, 0], [0, 0]
    S1_North, S1_South, S2_North, S2_South = 0, 0, 0, 0
    S1_absoluteneutral, S2_absoluteneutral, maxsway = 0,0,500
    northRegion, southRegion, stablerange, Mid = 0, 0, 100, 0
    absoluteNeutral, stepres, setHresolutionpercent = 32767, 100 , 100
    prevsensor1, prevsensor2, sensor1, sensor2 = 0, 0, 0, 0
    prevstartposition, count, tempcount, invertcount = 0, 0, 0, False
    use_extended_resolution, INT1fired, INT2fired = False, False, False
    encoderPosition, encoderResolution, inSync = 0, 0, False
    storedstartposition, storedsensor1state, storedsensor2state = 0, 0, 0
    use_extended_resolution, setresolution = False, 0
    haptics_duration, haptics_strength, haptics_ontime, haptics_state = 0, 0, 0, 0
    INTProcessed, INT1fired, INT2fired = True, False, False

    activesensorInterrupt = 1
    rotationrate, timetracker, timetomultiply, multiplier = 0, 0, 10, 10
    locksensorlevels = False
    alpha, prevsmoothsensor1, prevsmoothsensor2 = 0.01, 0, 0
    processS1_S_INT, processS1_N_INT, processS2_S_INT, processS2_N_INT =True, True, True, True 
    flagState = 0
    returnRateCount = False

    def __init__(self, *args):
        if len(args) == 2:
            self.sensor1_pin, self.sensor2_pin = ADC(Pin(args[0])), ADC(
                    Pin(args[1]))
            ...
        elif len(args) == 5:
            if args[4] == False:
                self.sensor1_pin, self.sensor2_pin = ADC(Pin(args[0])), ADC(
                    Pin(args[1]))
                self.SensorINTpin[0] = Pin(args[2], Pin.IN, Pin.PULL_UP)
                self.SensorINTpin[0].irq(trigger=Pin.IRQ_RISING, handler=self.singleSensor_INT)
                self.SensorINTpin[1] = Pin(self.args[3], Pin.IN, Pin.PULL_UP)
                self.SensorINTpin[1].irq(trigger=Pin.IRQ_RISING, handler=self.singleSensor_INT)
                self.useInterrupt = True
            elif args[4] == True:
                self.SensorINTpin[2] = Pin(args[0], Pin.IN, Pin.PULL_UP)
                self.SensorINTpin[2].irq(trigger=Pin.IRQ_RISING, handler=self.mainISR)
                self.SensorINTpin[0] = Pin(args[1], Pin.IN, Pin.PULL_UP)
                self.SensorINTpin[0].irq(trigger=Pin.IRQ_RISING, handler=self.mainISR)
                self.SensorINTpin[1] = Pin(args[2], Pin.IN, Pin.PULL_UP)
                self.SensorINTpin[1].irq(trigger=Pin.IRQ_RISING, handler=self.mainISR)
                self.SensorINTpin[3] = Pin(self.args[3], Pin.IN, Pin.PULL_UP)
                self.SensorINTpin[3].irq(trigger=Pin.IRQ_RISING, handler=self.mainISR)
                self.useInterrupt = True
                self.exclInterrupt = True
        else:
            raise Exception(
                "invalid arguments, expected two or five received  {}".format(len(args)))

    def mainISR(self,gpiopin): # 
        if gpiopin == self.get_sensorINTpin(3):
            self.processExINT(3)
            #print("3")
        elif gpiopin == self.get_sensorINTpin(1):
            self.processExINT(1)
            #print("1")
        elif gpiopin == self.get_sensorINTpin(2):
            self.processExINT(2)
            #print("2")
        elif gpiopin == self.get_sensorINTpin(4):
            self.processExINT(4)
            #print("4")
        ...
    def setExclINTmode(self, *args):
        if len(args) == 5:
            self.SensorINTpin[2] = Pin(args[0], Pin.IN, Pin.PULL_UP)
            self.SensorINTpin[2].irq(trigger=Pin.IRQ_RISING, handler=self.mainISR)
            self.SensorINTpin[0] = Pin(args[1], Pin.IN, Pin.PULL_UP)
            self.SensorINTpin[0].irq(trigger=Pin.IRQ_RISING, handler=self.mainISR)
            self.SensorINTpin[1] = Pin(args[2], Pin.IN, Pin.PULL_UP)
            self.SensorINTpin[1].irq(trigger=Pin.IRQ_RISING, handler=self.mainISR)
            self.SensorINTpin[3] = Pin(args[3], Pin.IN, Pin.PULL_UP)
            self.SensorINTpin[3].irq(trigger=Pin.IRQ_RISING, handler=self.mainISR)
            self.useInterrupt = True
            self.exclInterrupt = True
        else:
            raise Exception(
                "invalid arguments, expected two or five received  {}".format(len(args)))


    def invertCount(self, inv):
        self.invertcount = inv



    def set_adcresolution(self,res):
        if res == 12:
        
            self.ADCMaxRes = 4095
            self.absoluteNeutral = 2048
            self.bound = 400
            self.maxsway = 252
        
        elif (res == 10):
            self.ADCMaxRes = 1023
            self.absoluteNeutral = 512
            self.bound = 10
            self.maxsway = 50
        elif (res == 16):
            self.ADCMaxRes = 65535
            self.absoluteNeutral = 32767
            self.bound = 6000
            self.maxsway = 1000
	

    def set_poleStateValues(self, sensornum, np, nu, sp):
        if sensornum == 1:
            self.S1_Neutral[0] = np - self.bound
            self.S1_Neutral[1] = np + self.bound
            self.S1_North = np
            self.S1_South = sp
            self.S1_absoluteneutral = nu
        elif sensornum == 2:
            self.S2_Neutral[0] = np - self.bound
            self.S2_Neutral[1] = np + self.bound
            self.S2_North = np
            self.S2_South = sp
            self.S2_absoluteneutral = nu
        self.southRegion = self.Neutral[1] + self.stablerange
        self.northRegion = self.Neutral[0] - self.stablerange
        self.Neutral[0] = nu - self.bound
        self.Neutral[1] = nu + self.bound
        self.Mid = nu

    def initialize_encoder(self):
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
